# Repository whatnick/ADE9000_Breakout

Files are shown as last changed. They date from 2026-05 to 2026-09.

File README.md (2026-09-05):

# ADE9000 Breakout Board

Breadboard-compatible breakout for the Analog Devices [ADE9000](https://www.analog.com/en/products/ade9000.html) — a high-performance, multiphase energy and power quality monitoring IC.

The board follows the **test circuit from Figure 55 of the ADE9000 datasheet** (Rev. B, p. 28): all onboard passives (decoupling, RC anti-aliasing filters, crystal load caps, reset RC) are populated, power plus the analog channels are broken out to 0.1" headers, and the remaining digital signals are exposed on test pads to keep the board compact.

## 3D renders

These views are rendered from the populated KiCad assembly using the
project-local STEP models.

| Top isometric | Bottom isometric |
|---|---|
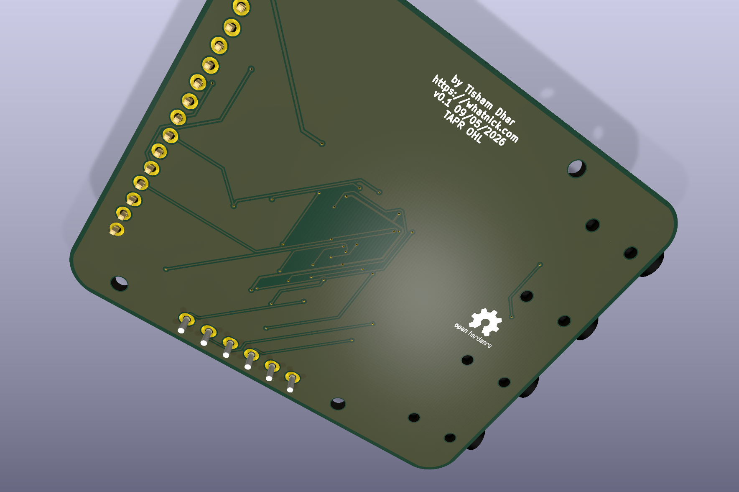
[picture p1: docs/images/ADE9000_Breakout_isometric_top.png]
ADE9000 breakout top isometric render
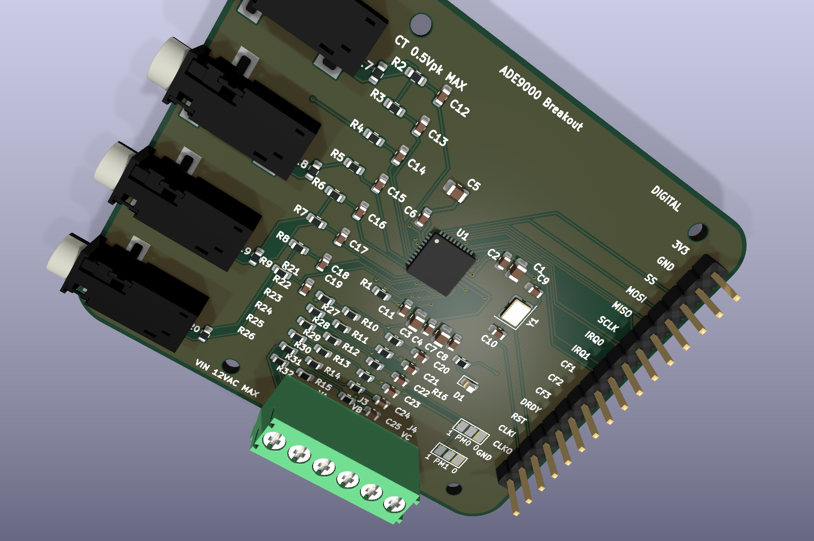
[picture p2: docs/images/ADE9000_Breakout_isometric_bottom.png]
ADE9000 breakout bottom isometric render
|  |  |

---

## Features

- **ADE9000** in 40-lead LFCSP (CP-40-7) package
- 3.3 V single-supply operation
- Onboard **24.576 MHz crystal** with 16 pF load caps (CLKIN/CLKOUT)
- Onboard **RC anti-aliasing filters** on all 7 analog input pairs (1 kΩ + 22 nF)
- Onboard **reset RC** (10 kΩ pull-up + 1 µF)
- Onboard **decoupling** on VDD, AVDDOUT, DVDDOUT, and REF per datasheet
- **CF2 activity LED** with 1 kΩ current-limit resistor
- **Power plus analog inputs** broken out to 0.1" headers
- **SPI, CF, IRQ, CLK, and RESET** exposed on test pads
- ATM90E36-style three-pad solder bridges for manual PM0/PM1 mode selection

---

## Pin Headers

### J1 — Power

| Pin | Signal | ADE9000 Pin | Description |
|-----|---|---|---|
| 1 | 3.3V | — | Power in |
| 2 | GND | — | Ground |

### J2 — Current Inputs (left side, top)

| Pin | Signal | ADE9000 Pin | Description |
|-----|---|---|---|
| 1 | IAP | 7 | Phase A current, positive |
| 2 | IAN | 8 | Phase A current, negative |
| 3 | IBP | 9 | Phase B current, positive |
| 4 | IBN | 10 | Phase B current, negative |
| 5 | ICP | 11 | Phase C current, positive |
| 6 | ICN | 12 | Phase C current, negative |
| 7 | INP | 13 | Neutral current, positive |
| 8 | INN | 14 | Neutral current, negative |

> Each input pair has a 1 kΩ series resistor and 22 nF cap to GND already fitted on board. Max differential input ±1 V / PGA gain.

### J3 — Voltage Inputs (left side, bottom)

| Pin | Signal | ADE9000 Pin | Description |
|-----|---|---|---|
| 1 | VAP | 20 | Phase A voltage, positive |
| 2 | VAN | 19 | Phase A voltage, negative |
| 3 | VBP | 22 | Phase B voltage, positive |
| 4 | VBN | 21 | Phase B voltage, negative |
| 5 | VCP | 24 | Phase C voltage, positive |
| 6 | VCN | 23 | Phase C voltage, negative |

> Each input pair has the same 1 kΩ + 22 nF RC filter as the current inputs.

### Test Pads — Digital I/O

| Pad | Signal | ADE9000 Pin | Description |
|-----|---|---|---|
| TP1 | SS | 40 | SPI slave select (active low) |
| TP2 | MOSI | 39 | SPI data in |
| TP3 | MISO | 38 | SPI data out |
| TP4 | SCLK | 37 | SPI clock (up to 20 MHz) |
| TP5 | IRQ0 | 31 | Interrupt output 0 (active low) |
| TP6 | IRQ1 | 32 | Interrupt output 1 (active low) |
| TP7 | CF1 | 33 | Calibration frequency output 1 |
| TP8 | CF2 | 34 | Calibration frequency output 2 / LED drive |
| TP9 | CF3_ZX | 35 | Zero-cross / CF3 output |
| TP10 | CF4_DREADY | 36 | Data-ready / event / CF4 output |
| TP11 | RESET | 6 | Reset (active low, RC-held high) |

---

## Power

- Supply **3.3 V** into the J1 3.3V pin (or the dedicated 3V3 pad).
- Current draw: ~15–17 mA in normal mode (PSM0).
- Onboard decoupling (per datasheet §Test Circuit):
  - **VDD** (pin 27): 10 µF + 0.1 µF ceramic to GND
  - **AVDDOUT** (pin 25): 4.7 µF + 0.1 µF ceramic to GND — **do not drive externally**
  - **DVDDOUT** (pin 3): 4.7 µF + 0.1 µF ceramic to GND — **do not drive externally**
  - **REF** (pin 16): 4.7 µF + 0.1 µF ceramic to REFGND (internal 1.25 V reference)

### PM0/PM1 mode bridges

`JP1` controls PM0 and `JP2` controls PM1. Each open three-pad jumper is marked
`1 PMx 0`: bridge the center pad to `1` for `+3V3`, or to `0` for `GND`.

| JP2 / PM1 | JP1 / PM0 | Selection |
|---|---|---|
| 0 | 0 | Normal operation |
| 0 | 1 | PM1:PM0 = `01` |
| 1 | 0 | PM1:PM0 = `10` |
| 1 | 1 | PM1:PM0 = `11` |

Bridge exactly one side of each jumper before powering the board. Never bridge
both sides, and do not leave a mode pin floating. Production boards intended
for normal operation should have the `0` side bridged on both JP1 and JP2.

---

## Clock

A 24.576 MHz crystal is fitted between CLKIN (pin 29) and CLKOUT (pin 30) with 16 pF load capacitors to GND. This matches the ADE9000's required ±30 ppm clock.

To use an external clock instead, remove the crystal, leave the load caps unpopulated, and drive CLKIN directly (3.3 V logic, 24.330–24.822 MHz, 45:55–55:45 duty cycle).

---

## SPI Interface

The ADE9000 uses **SPI mode 0** (CPOL=0, CPHA=0), MSB first, up to **20 MHz**.

| Signal | Direction (from MCU) | Notes |
|---|---|---|
| SCLK | Output | Max 20 MHz |
| MOSI | Output | 16-bit or 32-bit transfers |
| MISO | Input | |
| SS | Output | Assert low before each transfer |

All SPI pins are 3.3 V logic. Use a level shifter if connecting to a 5 V MCU.

---

## Analog Input Signal Conditioning

The onboard RC filter on each analog input pin:

```
Signal ──[ 1 kΩ ]──┬── IxP / VxP (ADE9000 pin)
                   │
                 [22 nF]
                   │
                  GND
```

This provides a first-order anti-aliasing LPF with fc ≈ 7.2 kHz, matching the ADC's −3 dB bandwidth. For CT or Rogowski coil inputs, drive the differential pair through an additional burden resistor or signal conditioning stage before these onboard filters.

---

## BOM Summary

Source purchasing fields live on the schematic symbols as `Manufacturer`, `MPN`, `DigiKey`, `Mouser`, and `Description` properties. Regenerate the grouped purchasing BOM with:

```powershell
& "C:\Program Files\KiCad\10.0\bin\python.exe" .\scripts\apply_bom_fields.py
& "C:\Program Files\KiCad\10.0\bin\python.exe" .\scripts\export_bom.py --html .\bom\ADE9000_Breakout_BOM.html
```

Generated outputs are available as [`bom/ADE9000_Breakout_BOM.csv`](bom/ADE9000_Breakout_BOM.csv), [`bom/ADE9000_Breakout_BOM.xlsx`](bom/ADE9000_Breakout_BOM.xlsx), and [`bom/ADE9000_Breakout_BOM.html`](bom/ADE9000_Breakout_BOM.html). The DigiKey and Mouser fields use distributor search URLs for the selected manufacturer MPNs so stock and packaging can be checked at order time.

| Ref | Value | Package | Notes |
|-----|---|---|---|
| U1 | ADE9000 | CP-40-7 LFCSP | Main IC |
| Y1 | 24.576 MHz | 3225 (3.2×2.5 mm) | ±30 ppm |
| C_CLKIN, C_CLKOUT | 16 pF | 0402 | Crystal load caps |
| C_VDD1 | 10 µF | 0805 | VDD bulk decoupling |
| C_VDD2, C_AVDD2, C_DVDD2, C_REF2 | 0.1 µF | 0402 | HF decoupling |
| C_AVDD1, C_DVDD1, C_REF1 | 4.7 µF | 0805 | LF decoupling |
| C_RST | 1 µF | 0402 | Reset RC |
| C_PM | 1 µF | 0402 | PM0 bypass |
| R_RST | 10 kΩ | 0402 | Reset pull-up |
| R_IAP…R_VCN (×14) | 1 kΩ | 0402 | Anti-aliasing series R |
| C_IAP…C_VCN (×7) | 22 nF | 0402 | Anti-aliasing cap (differential) |
| R_LED | 1 kΩ | 0402 | CF2 LED current limit |
| D_LED | Green LED | 0402 | CF2 activity indicator |

---

## Schematic

The KiCad schematic (`ADE9000_Breakout.kicad_sch`) implements Figure 55 of the datasheet with compact breakout constraints: only power and analog channels go to headers, while digital signals stay on test pads. Reference images and the datasheet are in [`docs/`](docs/).

---

## 3D CAD

Project-local STEP models for all populated ADE9000 board parts are stored in [`models/step/`](models/step/). The PCB references these files through `${KIPRJMOD}` so the 3D view and CAD export do not depend on a particular KiCad library installation.

The digital/debug header `J1` uses SparkFun's staggered `1x16_Locking` friction-fit footprint, vendored at [`footprints/SparkFun-Connector.pretty/1x16_Locking.kicad_mod`](footprints/SparkFun-Connector.pretty/1x16_Locking.kicad_mod) from `sparkfun/SparkFun-KiCad-Libraries` commit `14865e2`. It keeps the 2.54 mm header pitch but alternates pad positions by 0.127 mm so a standard breakaway male header can lock into the board without solder during bench use. The SparkFun library is licensed CC BY 4.0; attribution: SparkFun Electronics.

The stereo CT jacks use a black AP214-colored STEP model at [`models/step/Jack_3.5mm_CUI_SJ-3523-SMT_Horizontal.step`](models/step/Jack_3.5mm_CUI_SJ-3523-SMT_Horizontal.step), generated from the manufacturer `SJ-3523-SMT-TR` CAD ZIP in [`models/step/SJ_3523_SMT_TR.zip`](models/step/SJ_3523_SMT_TR.zip) with [`scripts/create_sj3523_smt_step.py`](scripts/create_sj3523_smt_step.py). The script bakes the DigiKey/Same Sky CAD into the KiCad footprint frame with the front barrel on the footprint's board-edge side, without adding artificial pad overlays. Do not substitute the through-hole `SJ1-3523N` model for this SMT footprint.

The voltage screw-terminal footprints use KiCad's 1x02 3.50 mm horizontal Phoenix STEP model as the closest installed mechanical equivalent for the 4Ucon footprint, with model-only offset `(-1.75, -0.05, 0)` to align the substitute body to the 4Ucon footprint outline.

A full board assembly STEP export is available at [`exports/step/ADE9000_Breakout.step`](exports/step/ADE9000_Breakout.step). Regenerate it with:

```powershell
& "C:\Program Files\KiCad\10.0\bin\kicad-cli.exe" pcb export step --force --subst-models --output "exports\step\ADE9000_Breakout.step" "ADE9000_Breakout.kicad_pcb"
```

---

## Resources

| Document | Path |
|---|---|
| ADE9000 Datasheet (Rev. B) | [`docs/ADE9000.pdf`](docs/ADE9000.pdf) |
| Test Circuit Reference | [`docs/images/test_ade9000.png`](docs/images/test_ade9000.png) |
| ADE9000 Product Page | https://www.analog.com/en/products/ade9000.html |
| ADE9000 Technical Reference Manual (UG-1098) | https://www.analog.com/media/en/technical-documentation/user-guides/ADE9000-UG-1098.pdf |
| Arduino Shield Eval (UG-1170) | https://www.analog.com/media/en/technical-documentation/user-guides/ev-ade9000shieldz-ug-1170.pdf |
| no-OS Driver | https://github.com/analogdevicesinc/no-OS/tree/main/drivers/meter/ade9000 |

---

## License

This hardware design is released under the [TAPR Open Hardware License v1.0](LICENSE). The PCB artwork includes a `TAPR OHL` notice on the back silkscreen.

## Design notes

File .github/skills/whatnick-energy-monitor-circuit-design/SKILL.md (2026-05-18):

---
name: whatnick-energy-monitor-circuit-design
description: "Use when: designing, reviewing, or regenerating energy-monitor schematics for ADE9000, ATM90E36, V9360, V9381, V9261F, MCP39xx, or similar metering breakouts. Covers datasheet circuits, analog input conditioning, current clamp burden/multiplier choices, power/reference/clock support circuits, connector policy, KiCad symbol connectivity, and ERC validation."
argument-hint: "target IC, schematic, or circuit block"
---

# Whatnick Energy Monitor Circuit Design

Use this skill for the electrical design of whatnick-style energy-monitor boards before PCB placement or routing. Start from the datasheet reference circuit, then adapt connector exposure and conditioning to the intended board format.

Reference designs:

- `c:/Users/tisha/dev/ADE9000_Breakout/ADE9000_Breakout.kicad_sch`
- `c:/Users/tisha/dev/ATM90E36_Breakout_KiCAD/ATM90E36_Breakout/ATM90E36_Breakout.kicad_sch`
- `c:/Users/tisha/dev/V93xx_Breakout/V9360_Breakout/V9360_Breakout.kicad_sch`
- `c:/Users/tisha/dev/V93xx_Breakout/V9381_Breakout/V9381_Breakout.kicad_sch`
- `c:/Users/tisha/dev/V9261F_Breakout/V9261F_Breakout.kicad_sch`
- `c:/Users/tisha/dev/MCP39xx_Breakout/MCP3909_Breakout/MCP3909_Breakout.kicad_sch`

## Circuit Intent

Build electrically correct monitor breakouts that are easy to instrument:

- Follow the target IC datasheet reference/test circuit first.
- Preserve project-local symbols and footprints for metering ICs; do not replace custom libraries with guessed global parts.
- Expose measurement inputs through connectors sized for the intended use: compact headers for small breakouts, stereo jacks and screw terminals for clamp/line-input bench boards.
- Keep debug/digital access compact and grouped, using a JST/debug connector or breadboard-friendly side header instead of scattering test pads across the board.
- Add onboard support circuits for supplies, reference outputs, reset, clock, and mode pins before optimizing the PCB.

## Datasheet-First Procedure

1. Identify the exact IC, package, and exposed-pad naming from the datasheet and part lookup.
2. Inspect the actual KiCad symbol geometry and pin names before wiring; never infer pin order from package drawings or symbol appearance.
3. Create or preserve a project-local symbol when the global KiCad library does not contain an exact part.
4. Implement the application circuit blocks:
   - supply input filtering and regulator/output decoupling
   - reference decoupling
   - analog anti-alias filters on voltage and current channels
   - reset pull-up/RC or supervisor connection where required
   - crystal, oscillator, or external clock network
   - mode straps and no-connects for datasheet-confirmed unused pins
5. Add `PWR_FLAG` symbols only where KiCad ERC needs proof that a net is driven.
6. Run ERC after every generated or bulk connectivity pass.

## Analog Input Conventions

Use explicit net names around every conditioning component:

- IC-side filtered nets use the IC signal name: `IAP`, `IAN`, `VAP`, `VAN`, and so on.
- Connector-side nets use a suffix such as `_J`, `_IN`, or the existing project convention when a series resistor separates the connector from the IC pin.
- Keep each differential or pseudo-differential pair easy to inspect in the schematic.
- Place shunt capacitors to `GND` only where the datasheet/filter design requires them.
- Keep voltage divider, burden, and multiplier resistor roles visually distinct from anti-alias series resistors.

Common patterns:

- ADE9000 Figure 55 style: 1 k series and 22 nF shunt anti-alias filters on analog inputs; decouple VDD, AVDDOUT, DVDDOUT, and REF.
- V93XX compact style: small series resistors and shunt capacitors near the monitor IC; preserve datasheet-specific values.
- ATM-style clamp boards: CT jack inputs feed conditioning networks, and voltage inputs use screw terminals and divider/filter networks sized for the measurement range.

## Current Clamp Support

When supporting YHDC or similar current-output clamps:

- Add a clearly labeled burden/multiplier resistor across each jack-side current pair.
- Keep burden resistors close to the input connector but before the IC-side anti-alias network.
- Use explicit pair nets such as `IAP_J`/`IAN_J`, `IBP_J`/`IBN_J`, `ICP_J`/`ICN_J`, and `INP_J`/`INN_J`.
- For the ADE9000 ATM-style board, R17-R20 are 2.4R 0603 burden/multiplier resistors across the four current jack pairs for hand assembly.

## Digital And Debug Policy

Choose the debug exposure based on board format:

- Compact breakouts: put power and analog measurement pins on 0.1 inch headers; place CF, IRQ, reset, clock, and other low-use digital signals on named bottom-side test pads.
- Compact ADE9000 JST policy: use `J1` as a 6-pin JST-SH connector for `+3V3`, `GND`, `SS`, `MOSI`, `MISO`, and `SCLK`; keep CF/IRQ/CLK/RESET on named test pads.
- Larger ATM-style boards: aggregate digital signals on one board side with a breadboard-friendly 0.1 inch header so logic-analyzer and MCU hookup is obvious.
- Keep signal names literal on debug connectors and test pads: `SS`, `MOSI`, `MISO`, `SCLK`, `IRQ0`, `CF1`, `RESET`, `CLKIN`, etc.

## KiCad Connectivity Rules

For generated or MCP-edited schematics, connectivity must be physical, not label-only:

- Prefer MCP `connect_to_net` when it uses the exact pin endpoint.
- If scripting manually, emulate `connect_to_net`: pin endpoint -> short wire stub -> net label at the stub end.
- Use exact pin endpoints for IC pins, passives, connectors, and test pads.
- Do not place bare labels on passive pin bodies or guessed component coordinates; this caused ERC-open nets in the ADE9000 work.
- Add no-connect markers only to datasheet-confirmed unused pins.

## ERC Validation

Run KiCad 10 ERC from the project root:

```powershell
& "C:\Program Files\KiCad\10.0\bin\kicad-cli.exe" sch erc --format json --output erc.json .\ADE9000_Breakout.kicad_sch
```

Acceptable schematic state:

- Zero ERC errors.
- No floating labels or unintended `multiple_net_names` violations.
- No unconnected monitor IC pins unless they have datasheet-backed no-connect markers.
- Warnings are understood and documented. `endpoint_off_grid` is placement/grid hygiene; fix alignment before changing proven connectivity.

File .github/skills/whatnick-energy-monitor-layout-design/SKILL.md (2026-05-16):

---
name: whatnick-energy-monitor-layout-design
description: "Use when: placing components, connectors, references, markings, or test pads on whatnick-style energy-monitor PCBs. Covers analog/digital partitioning, connector placement, decoupling placement, CT jack and screw terminal layout, silkscreen/reference rules, and deterministic KiCad Python placement workflows."
argument-hint: "target board or placement task"
---

# Whatnick Energy Monitor Layout Design

Use this skill after the circuit is defined and before routing. The goal is a board that is easy to wire, easy to probe, and friendly to the autorouter while keeping analog measurement paths short and readable.

Reference layouts:

- `c:/Users/tisha/dev/ADE9000_Breakout/ADE9000_Breakout.kicad_pcb`
- `c:/Users/tisha/dev/ADE9000_Breakout/scripts/place_pcb.py`
- `c:/Users/tisha/dev/ADE9000_Breakout/scripts/move_refs_to_silkscreen.py`
- `c:/Users/tisha/dev/ATM90E36_Breakout_KiCAD/ATM90E36_Breakout/ATM90E36_Breakout.kicad_pcb`
- `c:/Users/tisha/dev/V93xx_Breakout/V9360_Breakout/V9360_Breakout.kicad_pcb`
- `c:/Users/tisha/dev/V93xx_Breakout/V9381_Breakout/V9381_Breakout.kicad_pcb`

## Placement Intent

- Place the monitor IC first, usually near the center, with pin banks facing their related circuits.
- Keep analog conditioning between the field connector and the IC pin it serves.
- Put current inputs, voltage inputs, power/debug headers, and digital headers on board edges with readable pin order from the board edge.
- Keep high-touch connectors mechanically accessible; avoid burying screw terminals, jacks, or debug headers behind tall parts.
- Keep clock parts close to clock pins and away from noisy digital routing.
- Keep decoupling capacitors tight to the IC supply/reference pins with very short GND return paths.
- Use deterministic KiCad Python scripts for nontrivial board placement so the board can be regenerated.

## Analog And Digital Partitioning

- Put analog input connectors on one side or along the edge nearest the analog pin bank.
- Put digital/debug signals on the opposite side when board size allows.
- Keep SPI/UART/CF/IRQ/reset routing corridors away from current and voltage input filters.
- In compact boards, bottom-side test pads can reduce front-side crowding. In larger bench boards, prefer a grouped side header for digital signals.
- For ATM-style energy boards, stereo current jacks and voltage screw terminals should be grouped by channel and labeled so wiring order is obvious.

## Connector Placement Patterns

- Compact V93XX style: one 0.1 inch header and bottom-side test pads on a small rounded board.
- Compact ADE9000 JST style: `J1` JST-SH for power/SPI, `J2`/`J3` for analog pairs, bottom-edge test pads for CF/IRQ/clock/reset.
- ATM-style bench board: stereo jacks for current clamp inputs, screw terminals for voltage inputs, and a 0.1 inch digital/debug header along one side for breadboard or logic-analyzer access.
- Keep connector references visible on silkscreen and orient values on Fab only.

## Decoupling And Support Placement

- Place each decoupling capacitor adjacent to its associated IC pin; do not gather decouplers into a remote cluster.
- Pair AVDDOUT/DVDDOUT/REF capacitors with their pins and nearby GND access.
- Keep oscillator/crystal parts short, symmetric, and isolated from long digital traces.
- Place reset pull-ups/caps near reset pins unless a connector-driven reset path needs edge access.
- Place burden/multiplier resistors near the jack-side current pair before the anti-alias path enters the IC-side filter rows.

## Reference And Silkscreen Rules

- Reference designators live on the matching silkscreen layer: `F.SilkS` for front-side footprints and `B.SilkS` for back-side footprints.
- Values stay on Fab layers to keep silkscreen readable.
- Mounting-hole `H*` references and values are intentionally hidden.
- Keep every component, connector, and test-pad reference visible unless it is a mounting hole.
- Move or rotate references to avoid pads, copper, board edges, and other text.
- Use `scripts/move_refs_to_silkscreen.py` with KiCad 10 Python to bulk-migrate references from Fab to silkscreen.

Default silkscreen style:

- Compact labels: 0.8 mm text height and 0.2 mm stroke when DRC/project rules allow.
- Board identity on front when space allows.
- Attribution/version/OSHW logo on back after placement is stable.

## Deterministic KiCad Python Pattern

Run placement scripts with KiCad 10 Python:

```powershell
& "C:\Program Files\KiCad\10.0\bin\python.exe" .\scripts\place_pcb.py
```

Script guidelines:

- Define board geometry and connector/channel constants near the top.
- Use helpers such as `place`, `place_bottom`, and `set_net` instead of repeating coordinate logic.
- Load exact footprints with `pcbnew.FootprintLoad` when library naming differs from schematic symbols.
- For ADE9000, KiCad 10 lacks the exact `EP4.27x4.27mm` QFN footprint; load the `EP4.6x4.6mm` footprint and resize/renumber the exposed pad to `EP`.
- Place refs before adding new Edge.Cuts or mounting-hole shapes if KiCad SWIG collections are fragile.
- If new footprint fields need to be hidden after insertion, post-process the serialized `.kicad_pcb` properties when SWIG field objects are unstable.

PowerShell note: do not use bash heredocs. Use checked-in scripts or `python -c` one-liners.

## Layout DRC Gate

Before routing, DRC should have no placement/mechanical blockers:

- no `courtyards_overlap`
- no `copper_edge_clearance`
- no `hole_clearance` or `hole_to_hole`
- no `pth_inside_courtyard` or `npth_inside_courtyard`
- no `silk_overlap`, `silk_over_copper`, or `silk_edge_clearance` caused by new placement

Unconnected items are expected before routing; all other DRC issues should be understood before exporting DSN.

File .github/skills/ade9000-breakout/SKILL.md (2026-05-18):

---
name: ade9000-breakout
description: "Use when: making ADE9000_Breakout-specific schematic, PCB, routing, validation, or script changes. Layer this project overlay on top of the whatnick energy-monitor circuit-design, layout-design, routing, and pcb-size-shape skills. Covers ADE9000 Figure 55, KiCad 10 commands, local scripts, current ATM-style board facts, and known MCP/KiCad pitfalls."
argument-hint: "ADE9000 schematic, PCB, routing, or validation task"
---

# ADE9000 Breakout Project Overlay

Use this skill for ADE9000_Breakout-specific facts. For reusable design principles, also load the relevant topic skill:

- Circuit/schematic work: `whatnick-energy-monitor-circuit-design`
- BOM and MPN sourcing: `whatnick-energy-monitor-bom-sourcing`
- Component placement and silkscreen: `whatnick-energy-monitor-layout-design`
- Routing, GND planes, netclasses, and DRC: `whatnick-energy-monitor-routing`
- Board envelope, mounting holes, and connector edge plan: `whatnick-energy-monitor-pcb-size-shape`
- 3D model placement and STEP export: `whatnick-energy-monitor-layout-design`

## Current Board Intent

The current board is an ATM90E36-style ADE9000 bench breakout, not the older tiny header-only board.

- Board envelope: 65 mm x 55 mm with rounded corners and four M2 NPTH mounting holes.
- Current inputs: stereo jack style connectors, with YHDC current-output clamp support.
- Voltage inputs: screw terminals.
- Voltage screw-terminal inputs are scaled for 12 VAC AC/AC transformer inputs using 100 kOhm high-side divider resistors and 2.49 kOhm shunts before the existing 1 k / 22 nF ADE9000 anti-alias filters. Keep small passives as 0603 on F.Cu for easier hand soldering unless a specific assembly constraint overrides it.
- Digital/debug signals: aggregated on one side for breadboard/logical analyzer access.
- `J1` uses the project-local SparkFun `1x16_Locking` staggered/friction-fit footprint from `footprints/SparkFun-Connector.pretty`, placed at `(184.873, 86.1)` with -90 degree rotation so odd-numbered pads stay on the old `x=185.0` route centerline and pins 2-16 run downward.
- GND planes: filled on F.Cu and B.Cu.
- Power routing: `+3V3`, `AVDDOUT`, and `DVDDOUT` use the `Power` netclass with 0.25 mm tracks and 0.50/0.25 mm vias.
- 3D CAD: populated parts use project-local STEP models under `models/step/`; full assembly export lives at `exports/step/ADE9000_Breakout.step`.
- The CT jack STEP model must match the SMT `Jack_3.5mm_CUI_SJ-3523-SMT_Horizontal` footprint; do not substitute the through-hole `SJ1-3523N` model.
- Strip CT jack footprint outlines from F.SilkS on this board; the jacks intentionally overhang the left board edge, and separate `CTA`/`CTB`/`CTC`/`CTN` labels carry the readable silkscreen marking.
- Voltage screw terminals use the Phoenix 1x02 P3.50 mm STEP as a 4Ucon substitute with model offset `(-1.75, -0.05, 0)`; keep pads at the continuous 3.5 mm row positions `J2=155`, `J3=162`, `J4=169`.

The previous compact/JST policy remains useful historical context:

- Compact `J1`: 6-pin JST-SH for `+3V3`, `GND`, `SS`, `MOSI`, `MISO`, and `SCLK`.
- Compact `J2`/`J3`: analog current/voltage inputs.
- Compact `TP5` through `TP13`: CF, IRQ, clock, and reset signals on the lower board edge.
- Do not recreate obsolete compact `TP1` through `TP4` unless intentionally reverting to the older topology.

## Circuit Facts

- Follow the ADE9000 datasheet Figure 55 support circuit unless the user explicitly changes topology.
- `ADE9000_Breakout.kicad_sym` is the authoritative source for custom symbol geometry.
- The ADE9000 exposed-pad pin number is `EP`.
- Anti-alias filters use 1 k series resistors and 22 nF shunt capacitors on analog input paths.
- VDD, AVDDOUT, DVDDOUT, and REF need local decoupling near U1.
- Clock uses a 24.576 MHz crystal with load capacitors unless using an external clock.
- PM0/PM1 are grounded for normal operating mode.
- YHDC current-output clamp support uses R17-R20, 2.4R 0603 burden/multiplier resistors across the jack-side current pairs.
- Voltage terminal support uses R21-R26 as 100 kOhm high-side divider resistors and R27-R32 as 2.49 kOhm shunts, producing about 0.41 V peak at the divider node from a 12 VAC RMS transformer input before the 1 k ADE9000 filter resistor.

## Schematic Generation Rules

- Inspect actual symbol pin locations before assigning nets.
- For U1 and all passives/connectors/test pads, connect by exact pin endpoint.
- Prefer MCP `connect_to_net` when it uses the exact pin endpoint.
- If scripting raw connectivity, use pin endpoint -> short wire stub -> net label at the stub end.
- Do not use label-only connectivity on passive pins; it looked connected but left pins ERC-open in this project.
- Add `no_connect` only to intentionally unused pins.
- Run KiCad ERC immediately after rewiring.

ERC interpretation:

- `pin_not_connected` means the generator failed electrically.
- `multiple_net_names` usually means two labeled stubs were accidentally merged.
- `endpoint_off_grid` is placement/grid hygiene; fix grid/placement before reworking proven connectivity.

## PCB Script Flow

Primary scripts:

- `scripts/rewire_schematic.py`: deterministic schematic regeneration.
- `scripts/apply_bom_fields.py`: deterministic schematic sourcing fields for Manufacturer, MPN, DigiKey, Mouser, and Description.
- `scripts/export_bom.py`: grouped CSV/XLSX/HTML BOM export from schematic fields.
- `scripts/place_pcb.py`: deterministic footprint/net assignment and placement.
- `scripts/apply_mechanical.py`: rounded outline, M2 holes, and board markings.
- `scripts/move_refs_to_silkscreen.py`: visible reference designators on matching silkscreen layers.
- `scripts/clear_routes_text.py`: remove old `(segment ...)` and `(via ...)` blocks before rerouting.
- `scripts/clear_zones_text.py`: remove old `(zone ...)` blocks before rerouting.
- `scripts/apply_power_planes.py`: add F.Cu/B.Cu GND planes and enforce thicker power copper.

Run scripts with KiCad 10 Python:

```powershell
& "C:\Program Files\KiCad\10.0\bin\python.exe" .\scripts\place_pcb.py
```

PowerShell note: use semicolons for command chaining and avoid bash heredocs.

## Routing Facts

- Clear stale routes and zones before a fresh autoroute.
- Export fresh DSN with KiCad Python `pcbnew.ExportSpecctraDSN`; avoid stale MCP DSN export state.
- Route with the `Power` netclass already present in `.kicad_pro`; post-widening already-routed 0.15 mm power tracks caused clearance errors.
- Use GND planes instead of widening every GND trace.
- For KiCad 10 vias, avoid `PCB_VIA.GetWidth()` without layer context; use `GetFrontWidth()` or set width directly.
- `scripts/apply_power_planes.py` uses solid GND zone connections to avoid a starved thermal on U1 pad 28.

Installed Freerouting context:

- Router jar: `C:/Users/tisha/AppData/Roaming/kicad/10.0/freerouting/freerouting.jar`
- JRE 25: `C:/Users/tisha/AppData/Roaming/kicad/10.0/freerouting/jre/jdk-25.0.3+9-jre/bin/java.exe`

## Validation Commands

STEP export:

```powershell
& "C:\Program Files\KiCad\10.0\bin\kicad-cli.exe" pcb export step --force --subst-models --output exports\step\ADE9000_Breakout.step .\ADE9000_Breakout.kicad_pcb
```

ERC:

```powershell
& "C:\Program Files\KiCad\10.0\bin\kicad-cli.exe" sch erc --format json --output erc.json .\ADE9000_Breakout.kicad_sch
```

DRC:

```powershell
& "C:\Program Files\KiCad\10.0\bin\kicad-cli.exe" pcb drc --format json --output drc.json .\ADE9000_Breakout.kicad_pcb
```

Expected final PCB state:

- Zero DRC errors.
- Zero unconnected items.
- Remaining warnings are known library/text/silkscreen warnings unless the task is specifically to eliminate them.

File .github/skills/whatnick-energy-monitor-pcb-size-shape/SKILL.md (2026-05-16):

---
name: whatnick-energy-monitor-pcb-size-shape
description: "Use when: choosing board size, outline shape, connector edge allocation, mounting holes, rounded corners, or compact versus ATM-style mechanical form for whatnick energy-monitor PCBs. Covers V93XX compact boards, MCP3909 rounded corners, ADE9000 compact/JST and ATM-style board envelopes, M2 holes, and mechanical DRC constraints."
argument-hint: "target board, enclosure, or mechanical format"
---

# Whatnick Energy Monitor PCB Size And Shape

Use this skill when deciding the board envelope, rounded corners, mounting holes, connector edge plan, or compact-versus-bench-board form factor.

Reference boards:

- `c:/Users/tisha/dev/V93xx_Breakout/V9360_Breakout/V9360_Breakout.kicad_pcb`
- `c:/Users/tisha/dev/V93xx_Breakout/V9381_Breakout/V9381_Breakout.kicad_pcb`
- `c:/Users/tisha/dev/MCP39xx_Breakout/MCP3909_Breakout/MCP3909_Breakout.kicad_pcb`
- `c:/Users/tisha/dev/ATM90E36_Breakout_KiCAD/ATM90E36_Breakout/ATM90E36_Breakout.kicad_pcb`
- `c:/Users/tisha/dev/ADE9000_Breakout/ADE9000_Breakout.kicad_pcb`
- `c:/Users/tisha/dev/ADE9000_Breakout/scripts/apply_mechanical.py`

## Form Factor Choice

Choose the board size from how the user will connect to it:

- Compact breakout: use when the goal is a small module exposing IC power and measurement pins with minimal debug access.
- Compact JST debug board: use when SPI/debug needs a reliable cable connector but the board should remain small.
- ATM-style bench board: use when the board needs stereo CT jacks, screw terminals, grouped digital header access, and more comfortable probing.
- Do not force a compact outline when connectors or analog filters cause bad routing, inaccessible labels, or fragile probing.

## Compact Board Style

V9360, V9381, MCP3909, and the compact ADE9000 revisions are the small-board references.

- V93XX envelope is about 38.2 mm x 28.04 mm including edge stroke.
- Compact ADE9000 JST revision used about 38.1 mm x 38.0 mm.
- Keep headers on edges and test pads on the bottom side when front-side space is tight.
- Put optional logos and attribution on B.SilkS after routing space is known.
- Keep copper, test pads, mounting holes, and silkscreen clear of rounded or chamfered edges.

## ATM-Style Bench Board

Use the ATM90E36-style layout when the energy monitor board is a wiring/probing platform rather than a tiny module.

- Allocate one edge or side region for digital/debug signals on a 0.1 inch breadboard-friendly header.
- Group current inputs by channel using stereo jacks or similarly robust connectors.
- Group voltage inputs on screw terminals with readable phase/neutral order.
- Leave room for burden/multiplier resistors near current jacks and filter rows near the IC.
- Use the larger board area to reduce routing congestion and improve silkscreen readability, not to scatter circuit blocks.
- The current ADE9000 ATM-style board uses a 65 mm x 55 mm envelope with current jacks, voltage screw terminals, digital header, M2 holes, and GND planes.

## Rounded Corners And Mounting Holes

Use MCP3909 as the rounded-corner style reference and ADE9000 as the local M2 implementation reference.

- Use rounded corners when the board will be handled as a bench module.
- 5.08 mm corner radius is the established rounded-corner visual pattern.
- Use four M2 NPTH holes when board space allows.
- M2 holes should be NPTH circular pads with 2.2 mm drill and 2.2 mm pad size, no net, excluded from BOM and position files.
- Hide mounting-hole references and values by design.
- Keep mounting holes outside component courtyards and away from copper, zones, silkscreen, and connector keepouts.

## Edge Allocation

- Put field wiring connectors where cables naturally leave the board.
- Keep analog connector edges away from digital headers when board size allows.
- Reserve a clean routing corridor between each connector group and its IC pin bank.
- Put bottom-side test pads along a board edge rather than mid-board when they need routing access.
- For the ADE9000 compact JST revision, bottom-edge `TP5` through `TP13` preserve the SPI/JST fanout corridor; the older mid-board cluster blocks routing.

## Mechanical Scripts

For ADE9000 mechanical finishing:

```powershell
& "C:\Program Files\KiCad\10.0\bin\python.exe" .\scripts\apply_mechanical.py .\ADE9000_Breakout.kicad_pcb
```

Script principles:

- Keep board bbox constants explicit.
- Rebuild Edge.Cuts deterministically.
- Add mounting holes reproducibly.
- Reapply board markings after outline/hole regeneration when the local script owns those markings.
- Avoid re-querying fragile KiCad SWIG collections after adding/removing board drawings; collect what is needed before mutation.

## Mechanical DRC Gate

After changing size, shape, holes, or connector placement, DRC must not introduce:

- `copper_edge_clearance`
- `hole_clearance`
- `hole_to_hole`
- `npth_inside_courtyard`
- `pth_inside_courtyard`
- `courtyards_overlap`
- `silk_edge_clearance`
- `silk_overlap`
- `silk_over_copper`

If board size changes cause new routing congestion, revisit connector edge allocation before relaxing clearances.

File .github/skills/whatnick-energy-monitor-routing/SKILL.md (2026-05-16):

---
name: whatnick-energy-monitor-routing
description: "Use when: routing, autorouting, adding ground planes, configuring net classes, importing SES files, or validating DRC for whatnick-style energy-monitor PCBs. Covers analog routing priorities, power trace widths, GND planes, Freerouting workflow, KiCad 10 DSN/SES handling, and zero-error DRC expectations."
argument-hint: "target board or routing task"
---

# Whatnick Energy Monitor Routing

Use this skill once placement is DRC-clean. Route critical analog, clock, power, and return paths deliberately, and use autorouting only with rules that match the intended copper widths.

Reference scripts and boards:

- `c:/Users/tisha/dev/ADE9000_Breakout/ADE9000_Breakout.kicad_pcb`
- `c:/Users/tisha/dev/ADE9000_Breakout/ADE9000_Breakout.kicad_pro`
- `c:/Users/tisha/dev/ADE9000_Breakout/scripts/clear_routes_text.py`
- `c:/Users/tisha/dev/ADE9000_Breakout/scripts/clear_zones_text.py`
- `c:/Users/tisha/dev/ADE9000_Breakout/scripts/apply_power_planes.py`

## Routing Priorities

1. Confirm placement DRC is clean except expected unconnected items.
2. Route current and voltage input pairs with short, tidy paths through their filters.
3. Route reference, regulator output, and decoupling connections with short return loops.
4. Route clock/crystal nets short and away from SPI/CF/IRQ runs.
5. Route digital/debug signals after analog and clock paths have stable corridors.
6. Add or refill GND planes after critical routes are stable.
7. Run DRC and inspect both clearance errors and unconnected items.

## Net Classes And Widths

Keep `.kicad_pro` rules aligned with the board being validated; KiCad CLI DRC uses project constraints.

Compact QFN breakout rules:

- Default: 0.15 mm track width, 0.15 mm clearance, 0.45 mm vias, 0.20 mm via drills.
- This routes dense ADE9000 compact/JST layouts cleanly when test pads are placed along the lower board edge.

ATM-style ADE9000 rules:

- Default signal routing can remain 0.15 mm/0.15 mm for dense IC fanout.
- Use a `Power` netclass for `+3V3`, `AVDDOUT`, and `DVDDOUT` before routing:
  - 0.25 mm tracks
  - 0.50 mm vias
  - 0.25 mm via drills
  - 0.15 mm clearance
- Do not post-widen dense 0.15 mm routes blindly; it creates avoidable clearance errors. Export DSN after the Power netclass is in the project.
- Treat `REF` as a precision/reference node, not a bulk power rail, unless the circuit specifically requires otherwise.
- Use GND planes for return copper; do not widen every `GND` segment in dense analog areas.

## Ground Planes

- Use filled GND zones on both copper layers when board area allows.
- Keep zones inset from board edges and mounting holes enough to avoid copper-edge and hole-clearance issues.
- Refill zones after every routing or mechanical change.
- For the ADE9000 ATM-style board, `scripts/apply_power_planes.py` adds F.Cu/B.Cu GND planes and enforces thicker power routing.
- Solid GND zone pad connections avoid the starved thermal on ADE9000 U1 pad 28; thermal relief can be used elsewhere only when DRC remains clean.

## Freerouting Workflow

Use fresh DSN/SES files. Avoid stale in-memory board state.

```powershell
& "C:\Program Files\KiCad\10.0\bin\python.exe" .\scripts\clear_routes_text.py .\ADE9000_Breakout.kicad_pcb
& "C:\Program Files\KiCad\10.0\bin\python.exe" .\scripts\clear_zones_text.py .\ADE9000_Breakout.kicad_pcb
& "C:\Program Files\KiCad\10.0\bin\python.exe" -c "import pcbnew; board=pcbnew.LoadBoard(r'ADE9000_Breakout.kicad_pcb'); pcbnew.ExportSpecctraDSN(board, r'ADE9000_Breakout.dsn')"
& "C:\Users\tisha\AppData\Roaming\kicad\10.0\freerouting\jre\jdk-25.0.3+9-jre\bin\java.exe" -jar "C:\Users\tisha\AppData\Roaming\kicad\10.0\freerouting\freerouting.jar" -de .\ADE9000_Breakout.dsn -do .\ADE9000_Breakout.ses -mp 100
& "C:\Program Files\KiCad\10.0\bin\python.exe" -c "import pcbnew; path=r'ADE9000_Breakout.kicad_pcb'; board=pcbnew.LoadBoard(path); pcbnew.ImportSpecctraSES(board, r'ADE9000_Breakout.ses'); pcbnew.SaveBoard(path, board)"
```

After SES import, reapply mechanical/marking scripts if the board flow requires them, then add planes and run DRC.

Installed Freerouting context for this machine:

- Router jar: `C:/Users/tisha/AppData/Roaming/kicad/10.0/freerouting/freerouting.jar`
- JRE 25: `C:/Users/tisha/AppData/Roaming/kicad/10.0/freerouting/jre/jdk-25.0.3+9-jre/bin/java.exe`

## KiCad 10 API Notes

- Export DSN with KiCad Python `pcbnew.ExportSpecctraDSN`; the MCP DSN exporter can use stale copper.
- Import SES with `pcbnew.ImportSpecctraSES`.
- For KiCad 10 vias, do not call `PCB_VIA.GetWidth()` without a layer-aware context. Use `GetFrontWidth()` or set via width directly.
- Clear zones with `scripts/clear_zones_text.py` before rerouting if old filled zones interfere with DSN export or DRC diagnosis.

## DRC Validation

Run KiCad 10 DRC from the project root:

```powershell
& "C:\Program Files\KiCad\10.0\bin\kicad-cli.exe" pcb drc --format json --output drc.json .\ADE9000_Breakout.kicad_pcb
```

Final routed boards must have:

- Zero DRC errors.
- Zero unconnected items.
- No non-library violations introduced by routing, pours, holes, or silkscreen.
- Remaining warnings are understood, usually `lib_footprint_mismatch`, text size, or legacy silkscreen warnings unless the current task is to eliminate them.

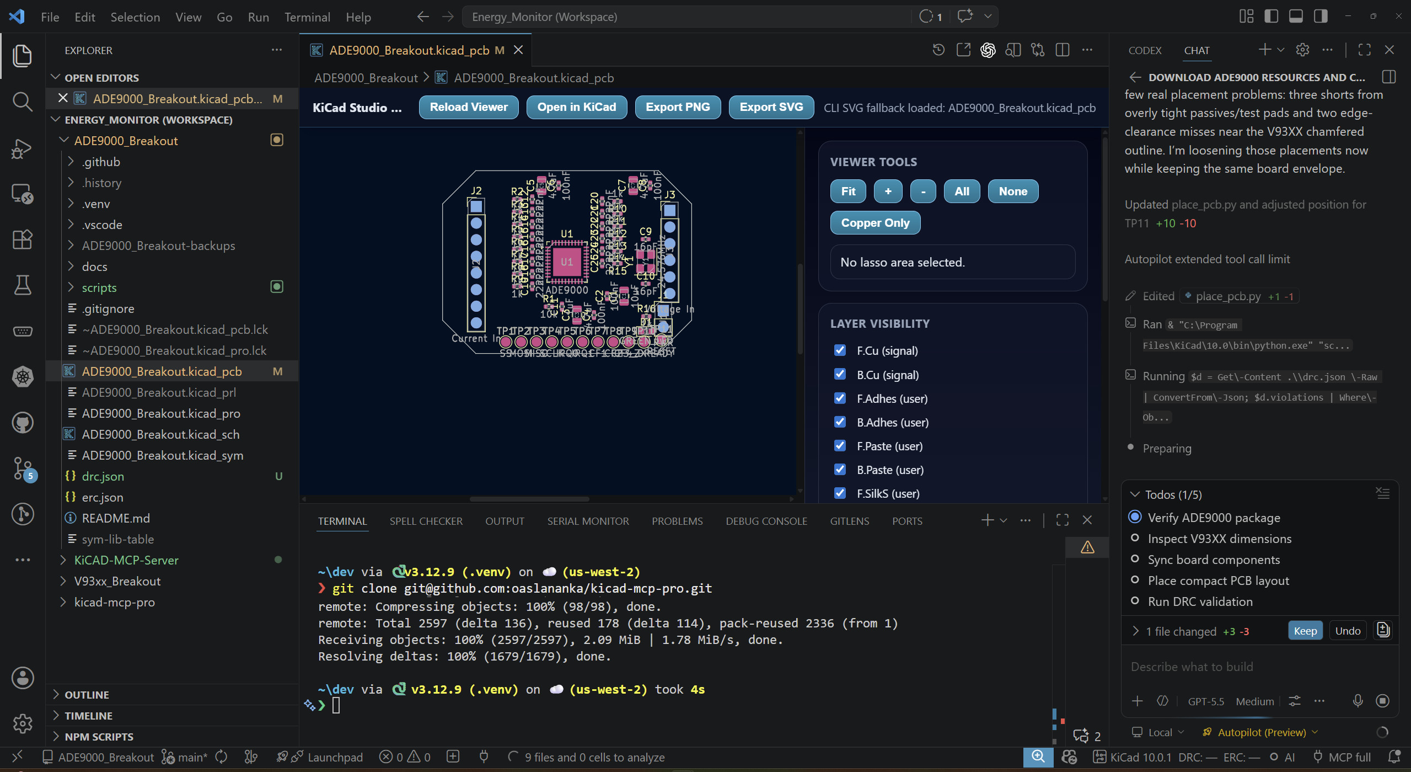
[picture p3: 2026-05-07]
docs/images/ai_aided_pcb.png

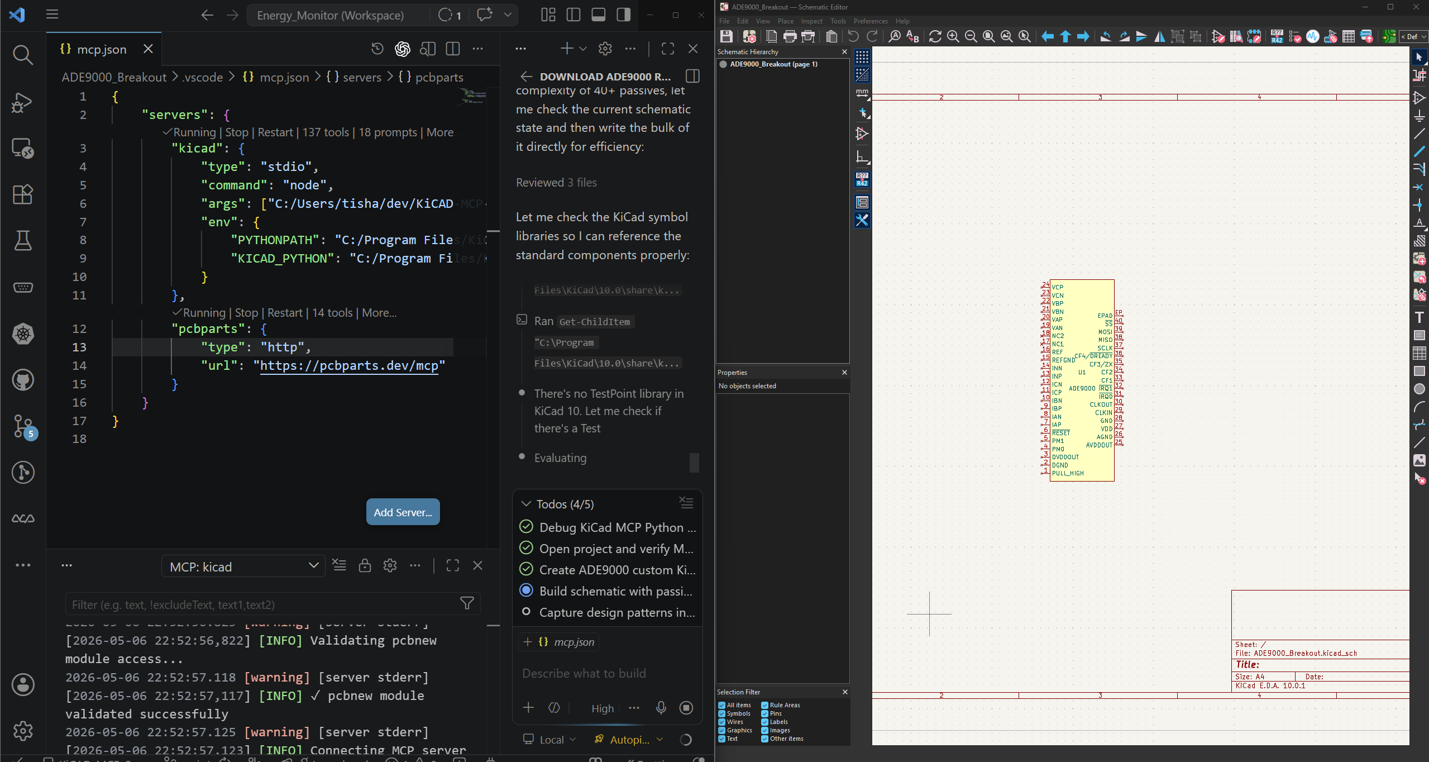
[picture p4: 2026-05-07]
docs/images/ai_aided_kicad.png

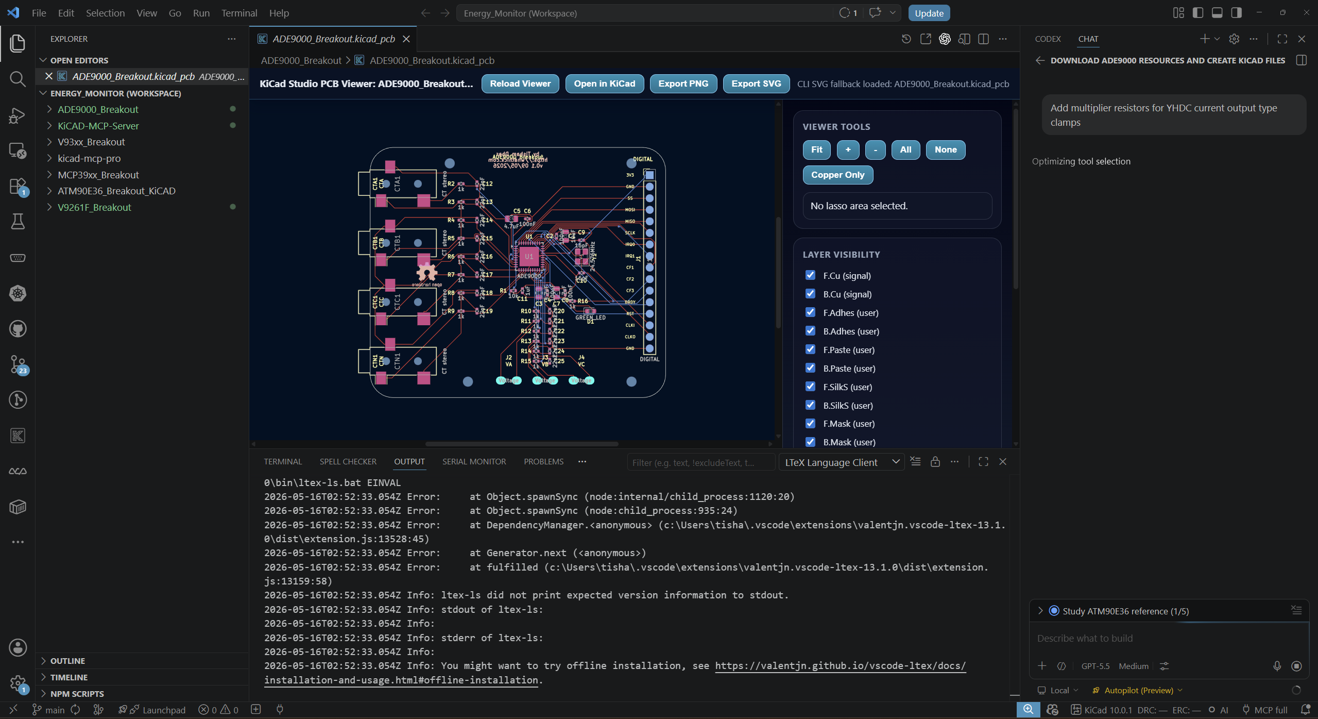
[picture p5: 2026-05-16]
docs/images/pivot_to_inputs_clamp.png

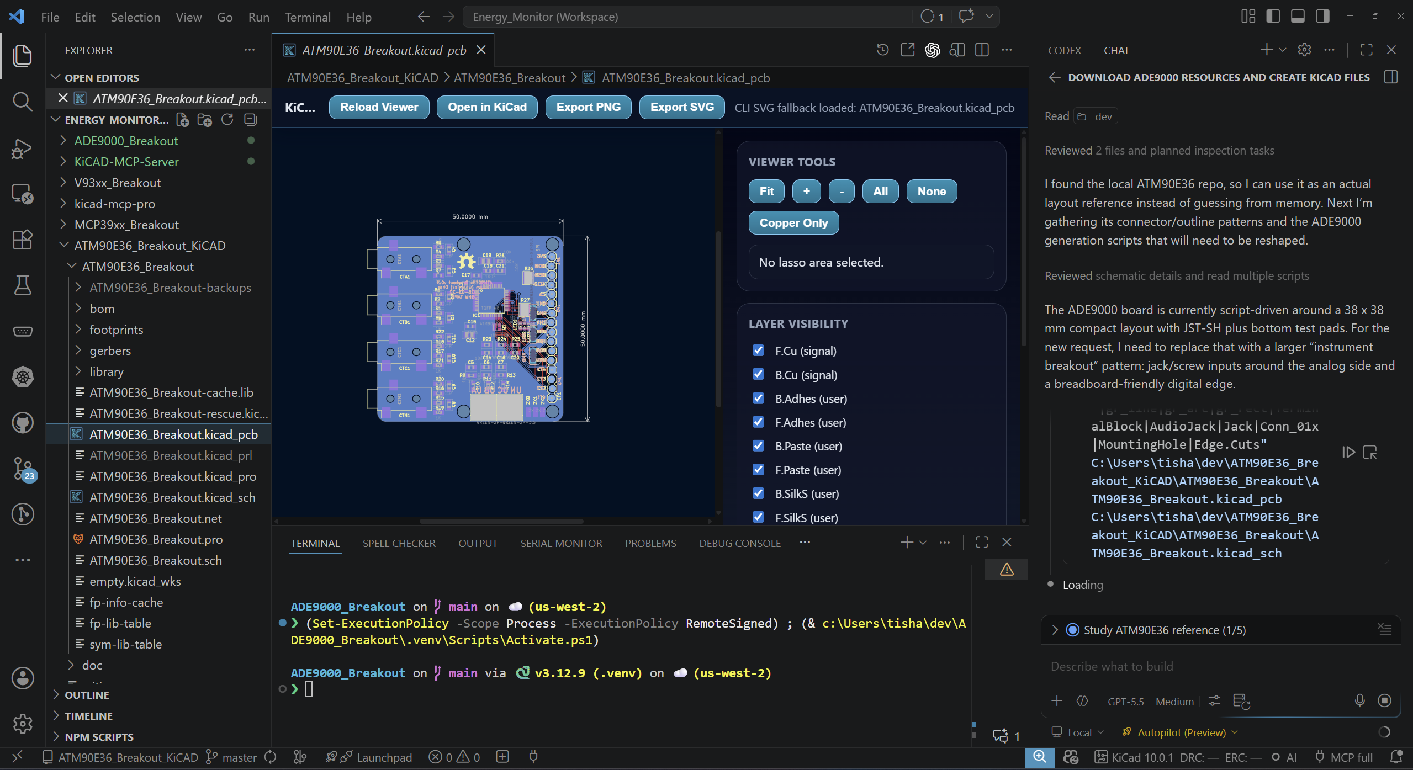
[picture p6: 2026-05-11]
docs/images/pivot_to_larger_board.png

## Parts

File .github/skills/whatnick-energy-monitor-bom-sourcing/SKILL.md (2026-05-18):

---
name: whatnick-energy-monitor-bom-sourcing
description: "Use when: choosing MPNs, creating BOMs, adding schematic sourcing fields, selecting DigiKey/Mouser parts, or standardizing passives/connectors across whatnick energy-monitor boards for bulk reel buying and reuse. Covers preferred common values, value normalization, substitution policy, distributor fields, and CSV/XLSX BOM export discipline."
argument-hint: "BOM, MPNs, DigiKey/Mouser sourcing, common passives, reel buying"
---

# Whatnick Energy Monitor BOM Sourcing

Use this skill when adding, reviewing, or regenerating BOM fields for whatnick energy-monitor boards. The sourcing goal is to reuse common values and manufacturers across boards so frequently used parts can be bought as reels and consumed across designs.

## Core Policy

- Put purchasing data on schematic symbols, not only in exported spreadsheets.
- Use the same preferred MPN for the same electrical value, package, dielectric, tolerance, and voltage rating wherever possible.
- Prefer reel-friendly commodity passives from stable high-volume families before optimizing for a one-off cheapest line item.
- Keep exact or mechanically constrained connectors as exact MPNs; do not substitute connectors just to share a line item if footprint, height, pitch, pinout, or 3D fit changes.
- Use distributor search URLs in `DigiKey` and `Mouser` fields unless a verified order-code field already exists in that project.
- Do not change precision, voltage rating, dielectric, power rating, package size, or temperature behavior to force reuse.
- Preserve measurement accuracy: burden, shunt, divider, reference, oscillator, and anti-alias parts may need tighter tolerance or lower tempco than generic passives.

## Preferred Common Parts

Use these as the first-choice values for new whatnick energy-monitor BOMs unless the circuit requires different electrical performance.

| Role | Value | Package | Preferred MPN | Manufacturer | Notes |
|---|---|---|---|---|---|
| Logic/reset pull-up, LED limit, generic bias | 1 kOhm 1% | 0402 | `RC0402FR-071KL` | YAGEO | Reuse for non-precision 1 k resistors. Do not use for precision dividers when tighter specs are needed. |
| Generic pull-up/pull-down | 10 kOhm 1% | 0402 | `RC0402FR-0710KL` | YAGEO | Default digital/config strap resistor. |
| YHDC current-output clamp burden/multiplier | 2.4 Ohm 1% | 0402 | `RC0402FR-072R4L` | YAGEO | Use only where power dissipation and measurement error budget are acceptable. |
| Local high-frequency decoupling | 100 nF X7R | 0402 | `GRM155R71A104KA01D` | Murata | Default 0402 decoupler. Raise voltage rating when rail or derating requires it. |
| Reset/reference small bypass | 1 uF X5R | 0402 | `GRM155R61A105KE15D` | Murata | Default compact 1 uF. Check DC bias for analog reference use. |
| Anti-alias shunt capacitor | 22 nF X7R | 0402 | `GRM155R71H223KA12D` | Murata | ADE9000-style 1 k/22 nF first-order filters. |
| Crystal load capacitor | 16 pF C0G/NP0 | 0402 | `GRM1555C1H160JA01D` | Murata | Use C0G/NP0 for oscillator stability. Adjust value for crystal load capacitance and stray capacitance. |
| Bulk rail decoupling | 4.7 uF X5R | 0805 | `CL21A475KPFNNNE` | Samsung Electro-Mechanics | Default 0805 low-frequency local/bulk capacitor. |
| Bulk input decoupling | 10 uF X5R | 0805 | `CL21A106KPFNNNE` | Samsung Electro-Mechanics | Default 0805 10 uF. Check DC bias and voltage derating. |
| Green status LED | Green 0603 | 0603 | `LTST-C191KGKT` | Lite-On | Shared indicator LED where color is not functionally constrained. |

For larger hand-assembled bench boards such as the ADE9000 ATM-style breakout, prefer 0603 equivalents for small passives while preserving the same electrical value, tolerance, dielectric, voltage rating, and measurement role. Current ADE9000 0603 choices are `RC0603FR-071KL`, `RC0603FR-0710KL`, `RC0603FR-072R4L`, `RC0603FR-07100KL`, `RC0603FR-072K49L`, `GRM188R71A104KA61D`, `GRM188R61A105KA61D`, `GRM188R71H223KA01D`, and `GRM1885C1H160JA01D`.

## Exact Mechanical Parts

These are shared where the matching footprint and mechanical envelope are intentionally used:

| Role | Preferred MPN | Manufacturer | Notes |
|---|---|---|---|
| ADE9000 CT stereo SMT jack | `SJ-3523-SMT-TR` | Same Sky | Must match `Jack_3.5mm_CUI_SJ-3523-SMT_Horizontal` and the project-local STEP model. |
| 3.5 mm 2-position voltage terminal | `1984617` | Phoenix Contact | Preferred 3.5 mm horizontal terminal substitute for ADE9000-style voltage terminals. Verify footprint against the target board. |
| 1x16 breakaway male header for SparkFun locking footprint | `PREC016SAAN-RC` | Sullins Connector Solutions | Header body used with SparkFun staggered/friction-fit PTH footprint. |

## Schematic Fields

For each sourced symbol, populate:

- `Manufacturer`
- `MPN`
- `Description`
- `DigiKey`
- `Mouser`

Use consistent field names across repositories so BOM exporters can group by MPN. If a board has legacy fields, preserve them only when required by its existing exporter and add the standard fields as well.

## Selection Workflow

1. Group parts by value, footprint, tolerance, voltage rating, dielectric, and role.
2. Match each group against the preferred common parts table.
3. Use the preferred MPN when the group is electrically equivalent or better for that role.
4. For special measurement or safety parts, choose the correct part first and document why it differs from the preferred list.
5. Add schematic fields, then export grouped CSV/XLSX BOM outputs from schematic data.
6. Review the grouped BOM for accidental fragmentation such as `100n`, `100nF`, and `0.1uF` exporting as separate lines.
7. Check live DigiKey/Mouser stock and packaging before ordering; distributor availability changes faster than the repository.

## When Not To Reuse

Choose a different MPN when any of these differ materially:

- ADC accuracy path needs tighter tolerance, tempco, voltage coefficient, or power rating.
- Capacitor dielectric or voltage rating affects filter frequency, reference noise, startup timing, or oscillator behavior.
- Connector must match an existing enclosure, mating cable, STEP model, board edge, or assembly process.
- The preferred part is end-of-life, unavailable in useful quantity, or no longer offered in reel-friendly packaging.

## Export Discipline

- Treat the schematic as BOM source of truth.
- Generated CSV/XLSX outputs are build artifacts derived from fields, but commit them when the repository uses BOM spreadsheets for ordering.
- Keep hand-edited iBOM output separate from sourced BOM commits unless the task is specifically to regenerate iBOM.
- Prefer exporter scripts over manual copy-paste from iBOM so the same preferred MPNs can be reused across boards.

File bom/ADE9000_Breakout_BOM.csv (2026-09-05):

Line | Quantity | References | Value | Footprint | Manufacturer | MPN | DigiKey | Mouser | Description
1 | 1 | C1 | 10uF | Capacitor_SMD:C_0805_2012Metric | Samsung Electro-Mechanics | CL21A106KPFNNNE | https://www.digikey.com/en/products/result?keywords=CL21A106KPFNNNE | https://www.mouser.com/c/?q=CL21A106KPFNNNE | 10 uF 10 V X5R 0805 ceramic capacitor
2 | 4 | C2, C4, C6, C8 | 100nF | Capacitor_SMD:C_0603_1608Metric | YAGEO | CC0603KPX7R0BB104 | https://www.digikey.com.au/en/products/detail/yageo/CC0603KPX7R0BB104/29291093 | https://www.mouser.com/c/?q=CC0603KPX7R0BB104 | 100 nF 100 V 10% X7R 0603 ceramic capacitor
3 | 3 | C3, C5, C7 | 4.7uF | Capacitor_SMD:C_0805_2012Metric | Samsung Electro-Mechanics | CL21A475KPFNNNE | https://www.digikey.com/en/products/result?keywords=CL21A475KPFNNNE | https://www.mouser.com/c/?q=CL21A475KPFNNNE | 4.7 uF 10 V X5R 0805 ceramic capacitor
4 | 2 | C9, C10 | 16pF | Capacitor_SMD:C_0603_1608Metric | Murata | GRM1885C1H160JA01D | https://www.digikey.com/en/products/result?keywords=GRM1885C1H160JA01D | https://www.mouser.com/c/?q=GRM1885C1H160JA01D | 16 pF 50 V C0G/NP0 0603 ceramic capacitor
5 | 1 | C11 | 1uF | Capacitor_SMD:C_0603_1608Metric | Murata | GRM188R61A105KA61D | https://www.digikey.com/en/products/result?keywords=GRM188R61A105KA61D | https://www.mouser.com/c/?q=GRM188R61A105KA61D | 1 uF 10 V X5R 0603 ceramic capacitor
6 | 14 | C12, C13, C14, C15, C16, C17, C18, C19, C20, C21, C22, C23, C24, C25 | 22nF | Capacitor_SMD:C_0603_1608Metric | Murata | GRM188R71H223KA01D | https://www.digikey.com/en/products/result?keywords=GRM188R71H223KA01D | https://www.mouser.com/c/?q=GRM188R71H223KA01D | 22 nF 50 V X7R 0603 ceramic capacitor
7 | 4 | CTA1, CTB1, CTC1, CTN1 | CT stereo jack | Connector_Audio:Jack_3.5mm_CUI_SJ-3523-SMT_Horizontal | Same Sky | SJ-3523-SMT-TR | https://www.digikey.com/en/products/result?keywords=SJ-3523-SMT-TR | https://www.mouser.com/c/?q=SJ-3523-SMT-TR | 3.5 mm stereo SMT audio jack for current-transformer inputs
8 | 1 | D1 | GREEN_LED | LED_SMD:LED_0603_1608Metric | Lite-On | LTST-C191KGKT | https://www.digikey.com/en/products/result?keywords=LTST-C191KGKT | https://www.mouser.com/c/?q=LTST-C191KGKT | Green 0603 SMD LED
9 | 1 | J1 | Digital breadboard | SparkFun-Connector:1x16_Locking | Sullins Connector Solutions | PREC016SAAN-RC | https://www.digikey.com/en/products/result?keywords=PREC016SAAN-RC | https://www.mouser.com/c/?q=PREC016SAAN-RC | 1x16 2.54 mm vertical breakaway male header for SparkFun locking footprint
10 | 3 | J2, J3, J4 | Voltage terminal | ADE9000-Local:TerminalBlock_4Ucon_1x02_P3.50mm_Horizontal_ADE9000 | Phoenix Contact | 1984617 | https://www.digikey.com/en/products/result?keywords=1984617 | https://www.mouser.com/c/?q=1984617 | 2-position 3.5 mm horizontal screw terminal block
11 | 1 | R1 | 10k | Resistor_SMD:R_0603_1608Metric | YAGEO | RC0603FR-0710KL | https://www.digikey.com/en/products/result?keywords=RC0603FR-0710KL | https://www.mouser.com/c/?q=RC0603FR-0710KL | 10 kOhm 1% 0603 thick-film resistor
12 | 15 | R2, R3, R4, R5, R6, R7, R8, R9, R10, R11, R12, R13, R14, R15, R16 | 1k | Resistor_SMD:R_0603_1608Metric | YAGEO | RC0603FR-071KL | https://www.digikey.com/en/products/result?keywords=RC0603FR-071KL | https://www.mouser.com/c/?q=RC0603FR-071KL | 1 kOhm 1% 0603 thick-film resistor
13 | 4 | R17, R18, R19, R20 | 2.4R | Resistor_SMD:R_0603_1608Metric | YAGEO | RC0603FR-072R4L | https://www.digikey.com/en/products/result?keywords=RC0603FR-072R4L | https://www.mouser.com/c/?q=RC0603FR-072R4L | 2.4 Ohm 1% 0603 thick-film burden resistor
14 | 6 | R21, R22, R23, R24, R25, R26 | 100k | Resistor_SMD:R_0603_1608Metric | YAGEO | RC0603FR-07100KL | https://www.digikey.com/en/products/result?keywords=RC0603FR-07100KL | https://www.mouser.com/c/?q=RC0603FR-07100KL | 100 kOhm 1% 0603 voltage-divider high-side resistor
15 | 6 | R27, R28, R29, R30, R31, R32 | 2.49k | Resistor_SMD:R_0603_1608Metric | YAGEO | RC0603FR-072K49L | https://www.digikey.com/en/products/result?keywords=RC0603FR-072K49L | https://www.mouser.com/c/?q=RC0603FR-072K49L | 2.49 kOhm 1% 0603 voltage-divider shunt resistor
16 | 1 | U1 | ADE9000 | Package_DFN_QFN:QFN-40-1EP_6x6mm_P0.5mm_EP4.27x4.27mm | Analog Devices | ADE9000ACPZ | https://www.digikey.com/en/products/result?keywords=ADE9000ACPZ | https://www.mouser.com/c/?q=ADE9000ACPZ | ADE9000 polyphase energy and power quality monitoring IC, CP-40-7 LFCSP
17 | 1 | Y1 | 24.576MHz | Crystal:Crystal_SMD_3225-4Pin_3.2x2.5mm | ECS Inc. | ECS-245.7-12-33Q-JES-TR | https://www.digikey.com/en/products/result?keywords=ECS-245.7-12-33Q-JES-TR | https://www.mouser.com/c/?q=ECS-245.7-12-33Q-JES-TR | 24.576 MHz 3.2 x 2.5 mm SMD crystal

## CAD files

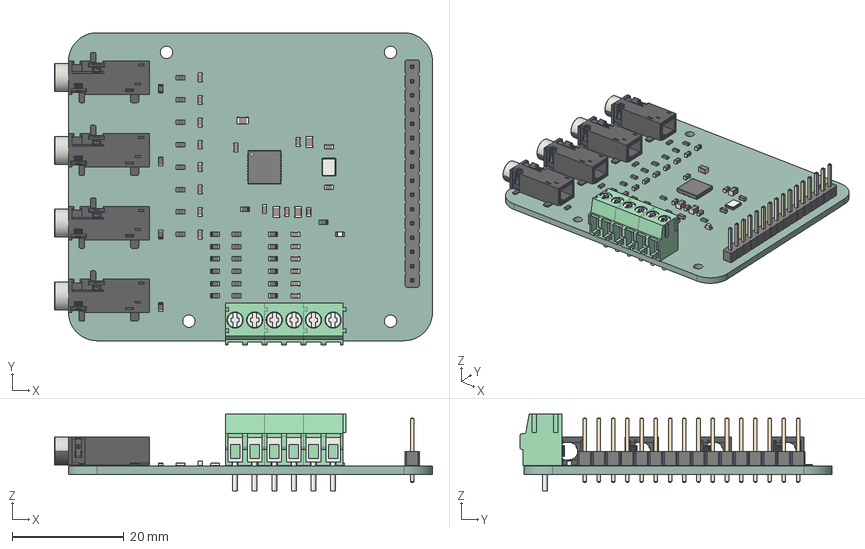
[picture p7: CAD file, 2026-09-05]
exports/step/ADE9000_Breakout.step
67.5 x 55.8 x 13.7 mm
C_0603_1608Metric x 21
R_0603_1608Metric x 32
TerminalBlock_Phoenix_PT-1,5-2-3.5-H_1x02_P3.50mm_Horizontal x 3
Jack_3.5mm_CUI_SJ-3523-SMT_Horizontal x 4
QFN-40-1EP_6x6mm_P0.5mm_EP4.6x4.6mm
C_0805_2012Metric x 4
Crystal_SMD_3225-4Pin_3.2x2.5mm
LED_0603_1608Metric
PinHeader_1x16_P2.54mm_Vertical
ADE9000_Breakout_PCB

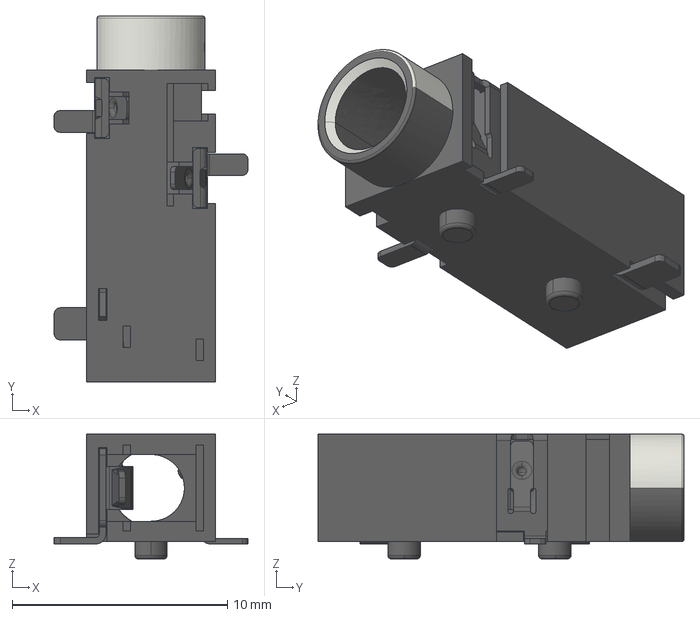
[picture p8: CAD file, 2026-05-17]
models/step/Jack_3.5mm_CUI_SJ-3523-SMT_Horizontal.step
9.00 x 17.0 x 5.80 mm

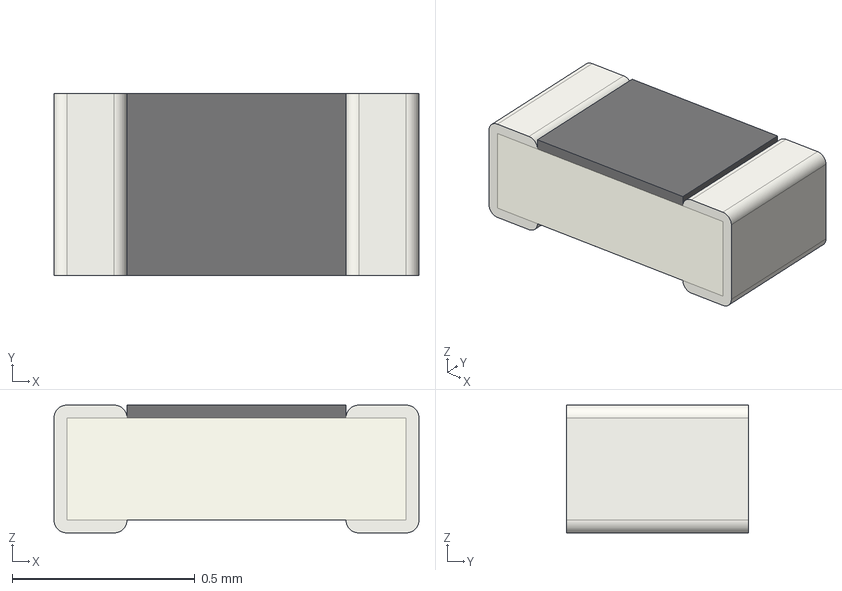
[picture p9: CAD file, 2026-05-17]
models/step/R_0402_1005Metric.step
1.00 x 0.5 x 0.35 mm

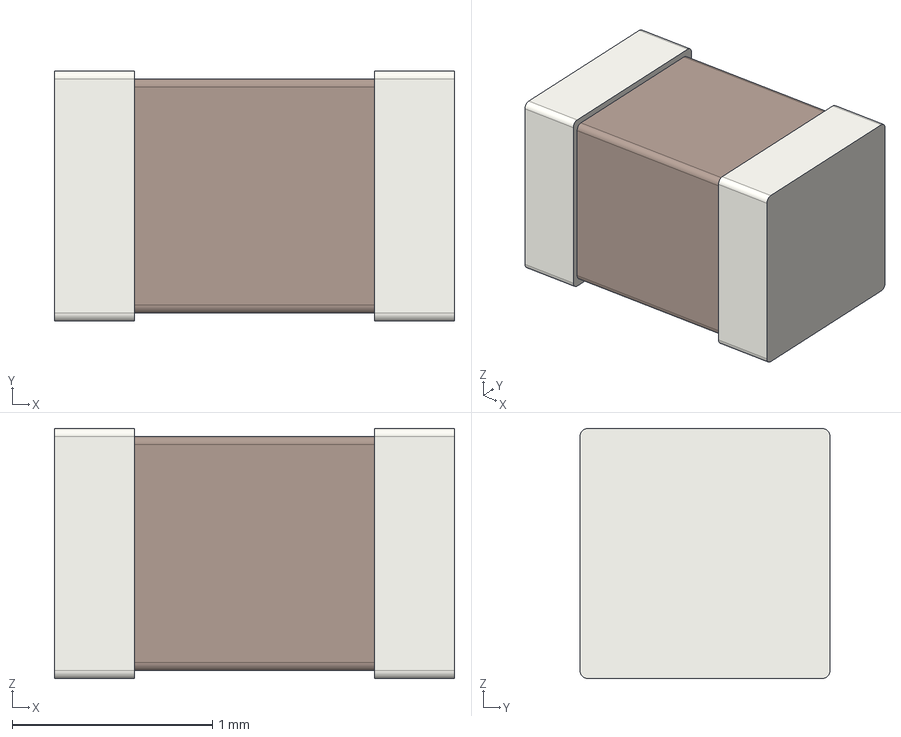
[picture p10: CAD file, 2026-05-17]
models/step/C_0805_2012Metric.step
2.00 x 1.25 x 1.25 mm

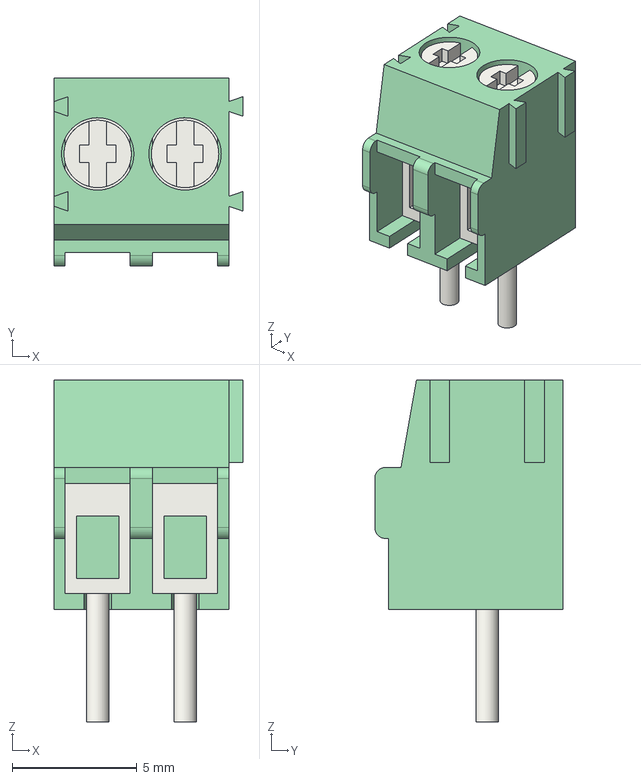
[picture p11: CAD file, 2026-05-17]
models/step/TerminalBlock_Phoenix_PT-1,5-2-3.5-H_1x02_P3.50mm_Horizontal.step
7.57 x 7.55 x 13.7 mm

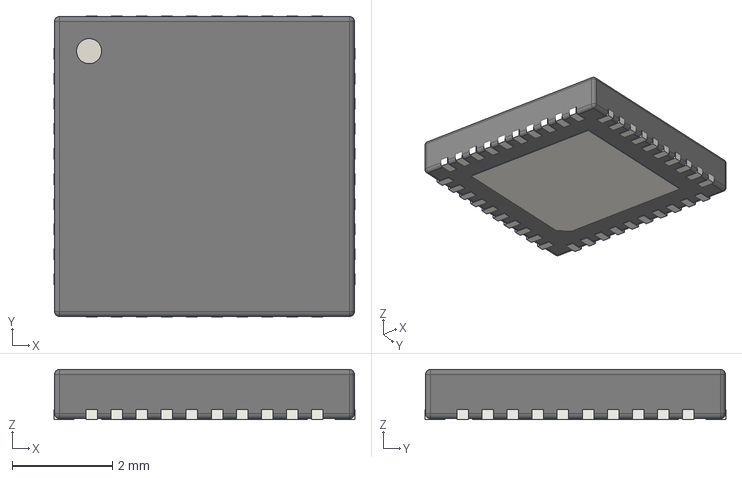
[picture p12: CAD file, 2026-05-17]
models/step/QFN-40-1EP_6x6mm_P0.5mm_EP4.6x4.6mm.step
6.00 x 6.00 x 1.00 mm

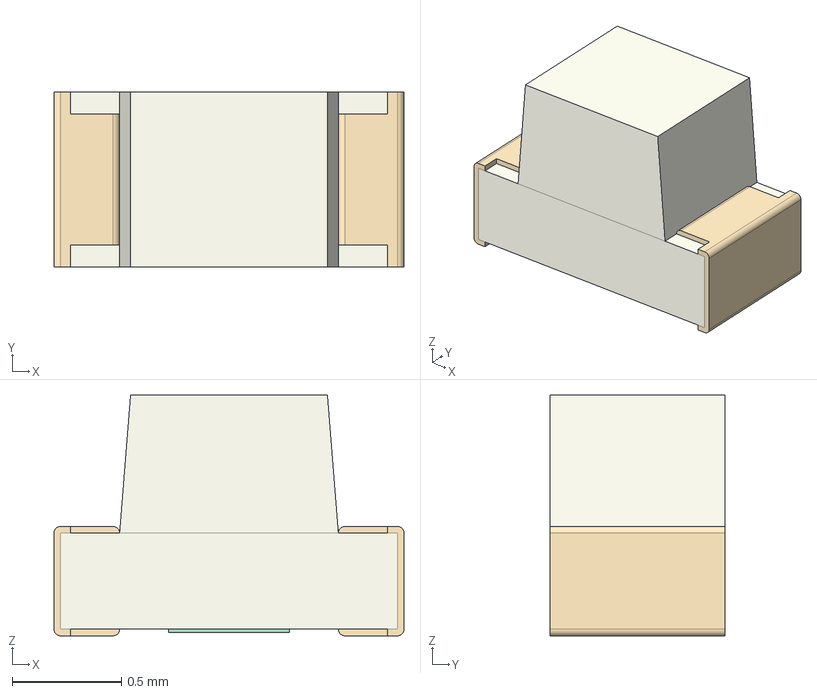
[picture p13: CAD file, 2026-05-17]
models/step/LED_0603_1608Metric.step
1.60 x 0.8 x 1.10 mm

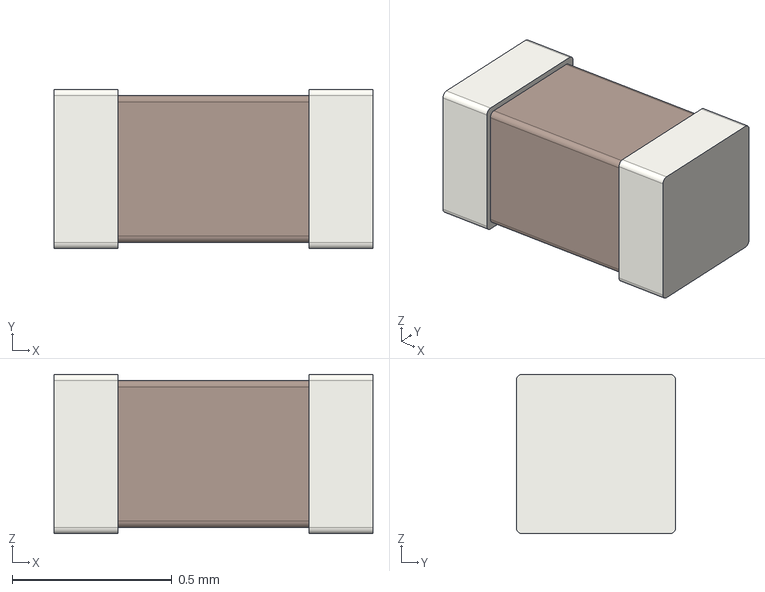
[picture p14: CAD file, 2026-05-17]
models/step/C_0402_1005Metric.step
1.00 x 0.5 x 0.5 mm

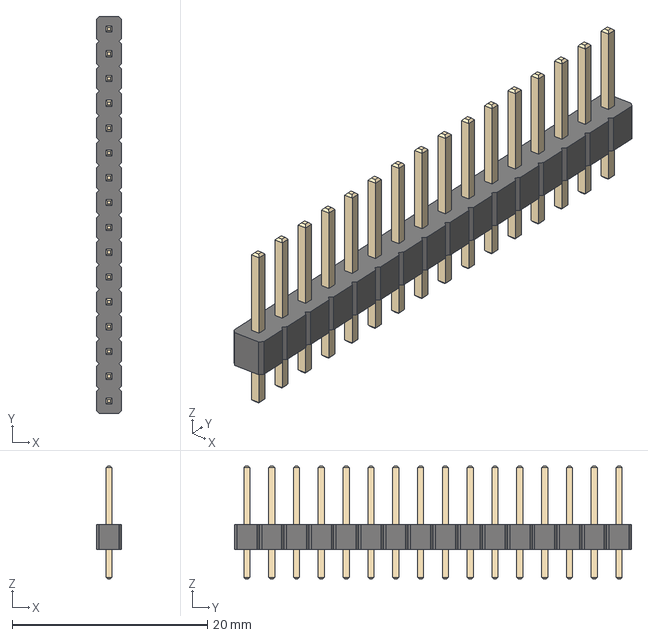
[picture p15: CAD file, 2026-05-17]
models/step/PinHeader_1x16_P2.54mm_Vertical.step
2.54 x 40.6 x 11.5 mm

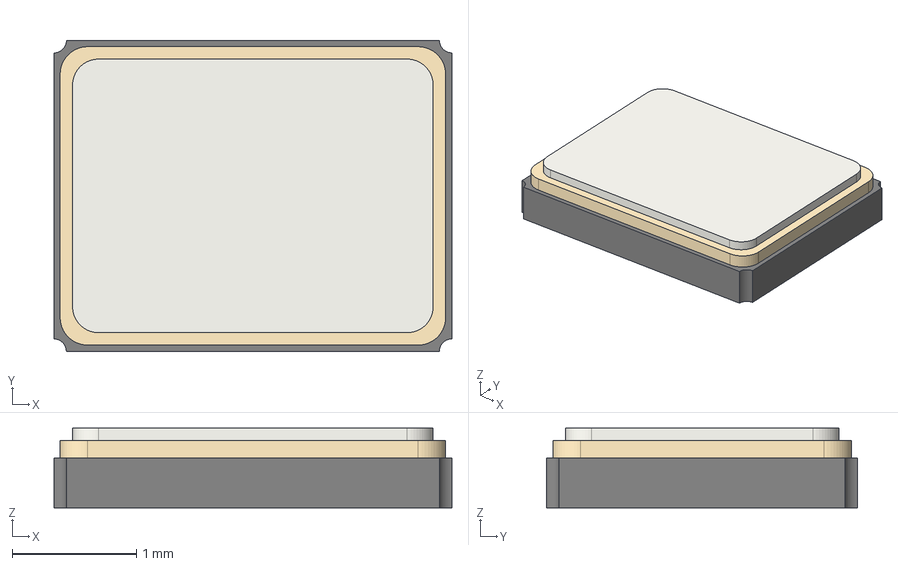
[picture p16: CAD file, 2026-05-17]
models/step/Crystal_SMD_3225-4Pin_3.2x2.5mm.step
3.20 x 2.50 x 0.64 mm

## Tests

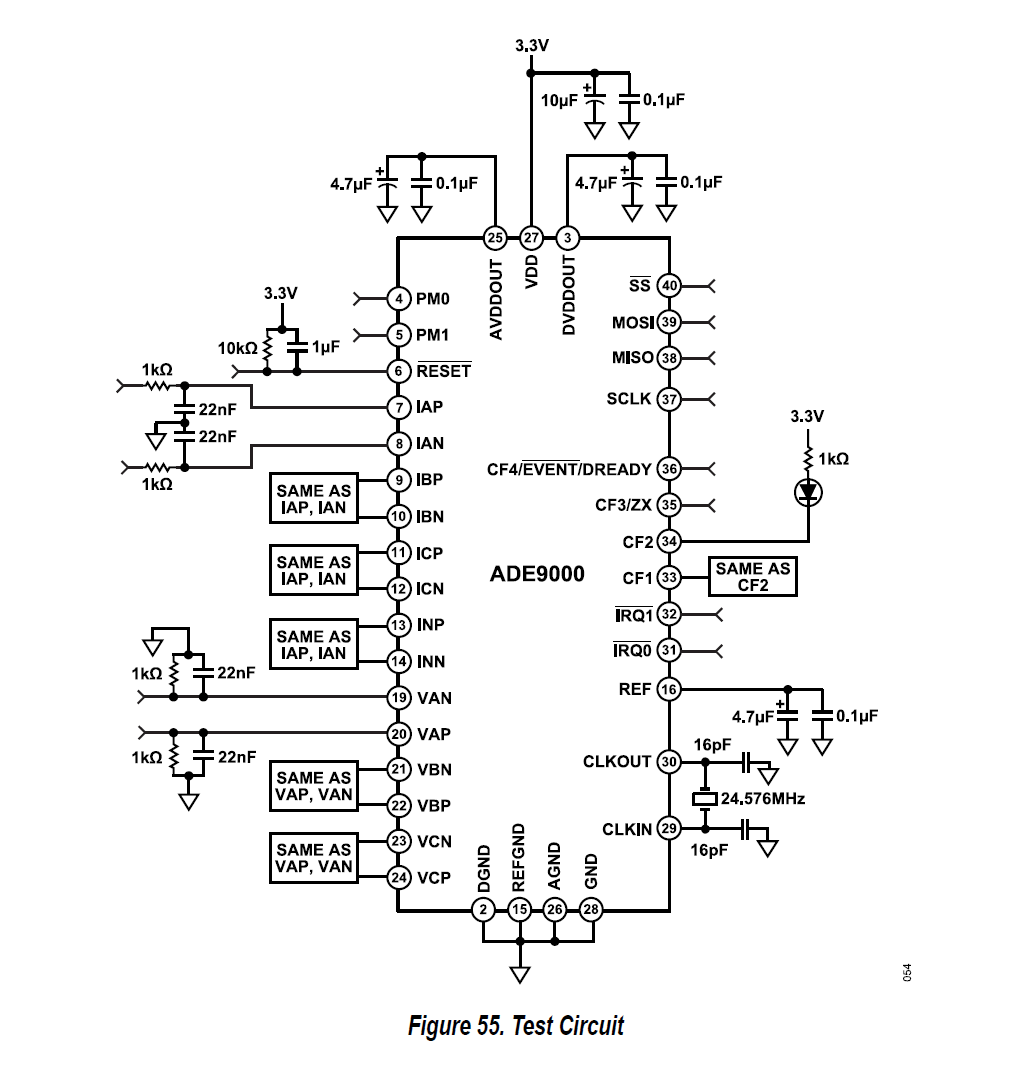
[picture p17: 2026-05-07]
docs/images/test_ade9000.png

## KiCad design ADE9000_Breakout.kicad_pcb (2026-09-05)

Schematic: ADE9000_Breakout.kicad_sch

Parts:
C1: 10uF; C_0805_2012Metric; MPN CL21A106KPFNNNE
C2, C4, C6, C8: 100nF; C_0603_1608Metric; MPN CC0603KPX7R0BB104
C3, C5, C7: 4.7uF; C_0805_2012Metric; MPN CL21A475KPFNNNE
C9, C10: 16pF; C_0603_1608Metric; MPN GRM1885C1H160JA01D
C11: 1uF; C_0603_1608Metric; MPN GRM188R61A105KA61D
C12, C13, C14, C15, C16, C17, C18, C19, C20, C21, C22, C23, C24, C25: 22nF; C_0603_1608Metric; MPN GRM188R71H223KA01D
CTA1: CT stereo jack; Jack_3.5mm_CUI_SJ-3523-SMT_Horizontal; MPN SJ-3523-SMT-TR
CTB1: CT stereo jack; Jack_3.5mm_CUI_SJ-3523-SMT_Horizontal; MPN SJ-3523-SMT-TR
CTC1: CT stereo jack; Jack_3.5mm_CUI_SJ-3523-SMT_Horizontal; MPN SJ-3523-SMT-TR
CTN1: CT stereo jack; Jack_3.5mm_CUI_SJ-3523-SMT_Horizontal; MPN SJ-3523-SMT-TR
D1: GREEN_LED; LED_0603_1608Metric; MPN LTST-C191KGKT
J1: Digital breadboard; 1x16_Locking; MPN PREC016SAAN-RC
J2, J3, J4: Voltage terminal; TerminalBlock_4Ucon_1x02_P3.50mm_Horizontal_ADE9000; MPN 1984617
JP1: PM0 mode; ModeBridge_3Pad
JP2: PM1 mode; ModeBridge_3Pad
R1: 10k; R_0603_1608Metric; MPN RC0603FR-0710KL
R2, R3, R4, R5, R6, R7, R8, R9, R10, R11, R12, R13, R14, R15, R16: 1k; R_0603_1608Metric; MPN RC0603FR-071KL
R17, R18, R19, R20: 2.4R; R_0603_1608Metric; MPN RC0603FR-072R4L
R21, R22, R23, R24, R25, R26: 100k; R_0603_1608Metric; MPN RC0603FR-07100KL
R27, R28, R29, R30, R31, R32: 2.49k; R_0603_1608Metric; MPN RC0603FR-072K49L
U1: ADE9000; QFN-40-1EP_6x6mm_P0.5mm_EP4.27x4.27mm; MPN ADE9000ACPZ
Y1: 24.576MHz; Crystal_SMD_3225-4Pin_3.2x2.5mm; MPN ECS-245.7-12-33Q-JES-TR

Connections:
+3V3: C1.2, C2.2, J1.1, JP1.1 (A), JP2.1 (A), R1.2, U1.1 (PULL_HIGH), U1.27 (VDD)
AVDDOUT: C3.2, C4.2, U1.25 (AVDDOUT)
CF1: J1.9, U1.33 (CF1)
CF2: J1.10, R16.2, U1.34 (CF2)
CF2_LED: D1.2 (A), R16.1
CF3_ZX: J1.11, U1.35 (CF3/ZX)
CF4_DREADY: J1.12, U1.36 (CF4/~DREADY)
CLKIN: C9.2, J1.14, U1.29 (CLKIN), Y1.1
CLKOUT: C10.2, J1.15, U1.30 (CLKOUT), Y1.2
DVDDOUT: C5.2, C6.2, U1.3 (DVDDOUT)
GND: C1.1, C2.1, C3.1, C4.1, C5.1, C6.1, C7.1, C8.1, C9.1, C10.1, C11.1, C12.2, C13.2, C14.2, C15.2, C16.2, C17.2, C18.2, C19.2, C20.2, C21.2, C22.2, C23.2, C24.2, C25.2, CTA1.R, CTB1.R, CTC1.R, CTN1.R, D1.1 (K), J1.2, J1.16, JP1.3 (B), JP2.3 (B), R27.2, R28.2, R29.2, R30.2, R31.2, R32.2, U1.2 (DGND), U1.15 (REFGND), U1.26 (AGND), U1.28 (GND), U1.EP (EPAD)
IAN: C13.1, R3.2, U1.8 (IAN)
IAN_J: CTA1.S, R3.1, R17.2
IAP: C12.1, R2.2, U1.7 (IAP)
IAP_J: CTA1.T, R2.1, R17.1
IBN: C15.1, R5.2, U1.10 (IBN)
IBN_J: CTB1.S, R5.1, R18.2
IBP: C14.1, R4.2, U1.9 (IBP)
IBP_J: CTB1.T, R4.1, R18.1
ICN: C17.1, R7.2, U1.12 (ICN)
ICN_J: CTC1.S, R7.1, R19.2
ICP: C16.1, R6.2, U1.11 (ICP)
ICP_J: CTC1.T, R6.1, R19.1
INN: C19.1, R9.2, U1.14 (INN)
INN_J: CTN1.S, R9.1, R20.2
INP: C18.1, R8.2, U1.13 (INP)
INP_J: CTN1.T, R8.1, R20.1
IRQ0: J1.7, U1.31 (~IRQ0)
IRQ1: J1.8, U1.32 (~IRQ1)
MISO: J1.5, U1.38 (MISO)
MOSI: J1.4, U1.39 (MOSI)
PM0: JP1.2 (C), U1.4 (PM0)
PM1: JP2.2 (C), U1.5 (PM1)
REF: C7.2, C8.2, U1.16 (REF)
RESET: C11.2, J1.13, R1.1, U1.6 (~RESET)
SCLK: J1.6, U1.37 (SCLK)
SS: J1.3, U1.40 (~SS)
VAN: C20.1, R10.2, U1.19 (VAN)
VAN_DIV: R10.1, R22.2, R28.1
VAN_J: J2.2, R22.1
VAP: C21.1, R11.2, U1.20 (VAP)
VAP_DIV: R11.1, R21.2, R27.1
VAP_J: J2.1, R21.1
VBN: C22.1, R12.2, U1.21 (VBN)
VBN_DIV: R12.1, R24.2, R30.1
VBN_J: J3.2, R24.1
VBP: C23.1, R13.2, U1.22 (VBP)
VBP_DIV: R13.1, R23.2, R29.1
VBP_J: J3.1, R23.1
VCN: C24.1, R14.2, U1.23 (VCN)
VCN_DIV: R14.1, R26.2, R32.1
VCN_J: J4.2, R26.1
VCP: C25.1, R15.2, U1.24 (VCP)
VCP_DIV: R15.1, R25.2, R31.1
VCP_J: J4.1, R25.1

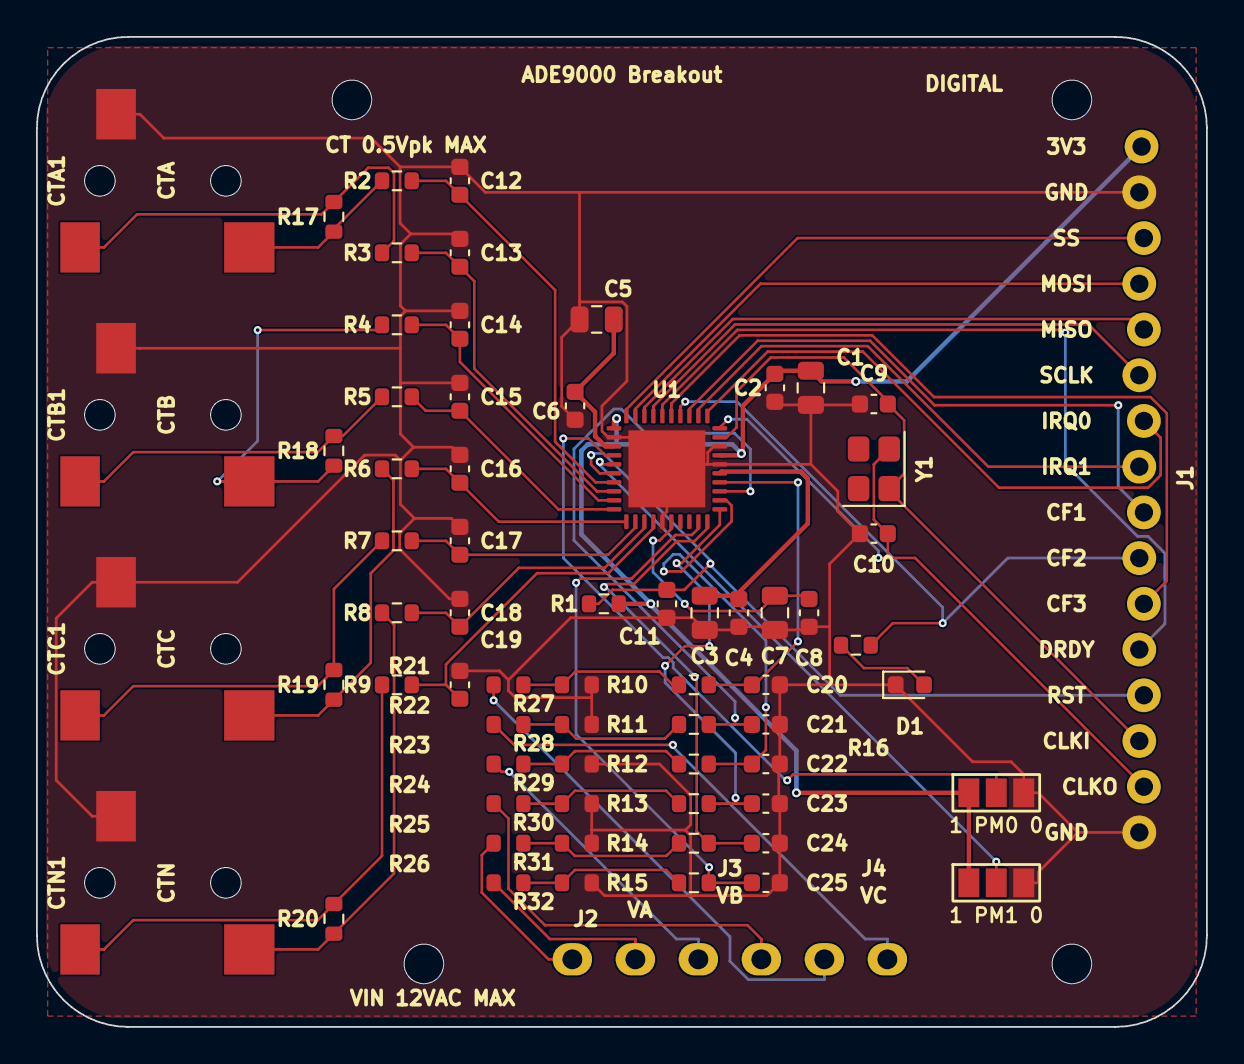
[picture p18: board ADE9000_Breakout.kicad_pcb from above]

Board: 2 copper layers, 65.0 x 55.0 mm, 75 parts (1 on the bottom side), 55 nets.

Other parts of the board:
H1, H2, H3, H4: MountingHole_2.2mm_M2
LOGO1: OSHW-LOGOM; OSHW-Logo2_7.3x6mm_SilkScreen

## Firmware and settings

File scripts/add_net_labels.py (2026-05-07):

"""
ADE9000 Breakout Board - Net Label Adder
Adds all net labels to connect schematic components.

Net strategy:
- J1 pin1 → +3V3 label
- J1 pin2 → GND label
- J2/J3 connector pins → IAP_J, IAN_J ... nets (left side of resistors)
- Resistors R2..R15 connect IAP_J → IAP through 1kΩ
- Caps C12..C25 connect node IAP etc → GND
- U1 analog pins get IAP, IAN... labels
- U1 digital pins get test pad labels
- Test pads TP1..TP11 get matching labels
- Power ties: PULL_HIGH→+3V3, PM0→GND, PM1→GND, DGND→GND, AGND→GND, REFGND→GND, EPAD→GND

Label angle convention:
- angle=0   → label faces RIGHT (normal, wire extends to the left)
- angle=180 → label faces LEFT (wire extends to the right)
"""
import sys
import json
import subprocess

SCH_PATH = r"c:\Users\tisha\dev\ADE9000_Breakout\ADE9000_Breakout.kicad_sch"
KI_IFACE = r"c:\Users\tisha\dev\KiCAD-MCP-Server\python\kicad_interface.py"
KI_PYTHON = r"C:\Program Files\KiCad\10.0\bin\python.exe"

def call_iface(command: str, params: dict):
    payload = json.dumps({"command": command, "params": params})
    result = subprocess.run(
        [KI_PYTHON, KI_IFACE],
        input=payload, capture_output=True, text=True, timeout=30
    )
    try:
        data = json.loads(result.stdout)
    except Exception:
        data = {"success": False, "stdout": result.stdout, "stderr": result.stderr}
    if not data.get("success"):
        print(f"  WARN: {command} '{params.get('label', params.get('x', ''))}' failed: {data.get('message', data)[:80]}", file=sys.stderr)
    return data

def label(net: str, x: float, y: float, angle: int = 0):
    return call_iface("add_schematic_net_label", {
        "schematicPath": SCH_PATH,
        "netName": net,
        "position": [x, y],
        "orientation": angle,
    })

def no_connect(x: float, y: float):
    return call_iface("add_no_connect", {
        "schematicPath": SCH_PATH, "position": [x, y]
    })

ok = lambda r: "✓" if r.get("success") else "✗"

print("=== ADE9000 Net Label Adder ===\n")

# ─── PIN POSITIONS ─────────────────────────────────────────────────────────────
# U1 left pins wire at x=117.3; U1 right pins wire at x=142.7
U1_LX = 117.3
U1_RX = 142.7

# For labels ON U1 left wires (facing left, so net comes from left):
# angle=0 means text faces right → the wire end attaches left of label
# We want a label pointing INTO the wire end at x=117.3
# Use angle=180 so the connection point is on the RIGHT side of the label,
# placed just past the wire end.
# KiCad net label: the connection stub is at the label origin (x,y).
# angle=0: connection stub on left, text extends right.
# angle=180: connection stub on right, text extends left.
# For U1 left pins, wire ends are at x=117.3 pointing LEFT (toward x<117.3).
# So we place label at x=117.3 with angle=0 (stub on left matches wire going left).
# For U1 right pins, wire ends at x=142.7 pointing RIGHT (toward x>142.7).
# Place label at x=142.7 with angle=180 (stub on right matches wire going right).

print("--- U1 Left Pin Labels (analog + control) ---")
left_pin_labels = [
    # (net_name, x, y)
    ("+3V3",   U1_LX, 70.79),   # PULL_HIGH  (pin1)  → +3V3
    ("GND",    U1_LX, 73.33),   # DGND       (pin2)  → GND
    # DVDDOUT (pin3) gets its own node: DVDDOUT net (power output)
    ("GND",    U1_LX, 78.41),   # PM0        (pin4)  → GND (SPI mode)
    ("GND",    U1_LX, 80.95),   # PM1        (pin5)  → GND (normal mode)
    ("RESET",  U1_LX, 83.49),   # ~RESET~    (pin6)
    # Analog current inputs
    ("IAP",    U1_LX, 86.03),
    ("IAN",    U1_LX, 88.57),
    ("IBP",    U1_LX, 91.11),
    ("IBN",    U1_LX, 93.65),
    ("ICP",    U1_LX, 96.19),
    ("ICN",    U1_LX, 98.73),
    ("INP",    U1_LX, 101.27),
    ("INN",    U1_LX, 103.81),
    ("GND",    U1_LX, 106.35),  # REFGND     (pin15) → GND
    ("REF",    U1_LX, 108.89),  # REF output (pin16)
    # NC1/NC2 → no-connect, handled separately
    # Analog voltage inputs
    ("VAN",    U1_LX, 116.51),
    ("VAP",    U1_LX, 119.05),
    ("VBN",    U1_LX, 121.59),
    ("VBP",    U1_LX, 124.13),
    ("VCN",    U1_LX, 126.67),
    ("VCP",    U1_LX, 129.21),
]

for net, x, y in left_pin_labels:
    r = label(net, x, y, angle=0)
    print(f"  {ok(r)} label '{net}' @ ({x}, {y:.2f})")

# DVDDOUT output node label
r = label("DVDDOUT", U1_LX, 75.87, angle=0)
print(f"  {ok(r)} label 'DVDDOUT' @ ({U1_LX}, 75.87)")

print()
print("--- U1 Right Pin Labels (power + SPI + CF) ---")
right_pin_labels = [
    # (net_name, x, y)
    ("AVDDOUT", U1_RX, 79.68),   # pin25
    ("GND",     U1_RX, 82.22),   # AGND (pin26) → GND
    ("+3V3",    U1_RX, 84.76),   # VDD  (pin27) → +3V3 in
    ("GND",     U1_RX, 87.30),   # GND  (pin28)
    ("CLKIN",   U1_RX, 89.84),   # CLKIN (pin29)
    ("CLKOUT",  U1_RX, 92.38),   # CLKOUT (pin30)
    ("IRQ0",    U1_RX, 94.92),   # ~IRQ0~ (pin31)
    ("IRQ1",    U1_RX, 97.46),   # ~IRQ1~ (pin32)
    ("CF1",     U1_RX, 100.00),  # CF1 (pin33)
    ("CF2",     U1_RX, 102.54),  # CF2 (pin34)
    ("CF3_ZX",  U1_RX, 105.08),  # CF3/ZX (pin35)
    ("CF4_DREADY", U1_RX, 107.62),  # CF4/DREADY (pin36)
    ("SCLK",    U1_RX, 110.16),  # SCLK (pin37)
    ("MISO",    U1_RX, 112.70),  # MISO (pin38)
    ("MOSI",    U1_RX, 115.24),  # MOSI (pin39)
    ("SS",      U1_RX, 117.78),  # ~SS~ (pin40)
    ("GND",     U1_RX, 120.32),  # EPAD → GND
]

for net, x, y in right_pin_labels:
    r = label(net, x, y, angle=180)
    print(f"  {ok(r)} label '{net}' @ ({x}, {y:.2f})")

# ─── NO-CONNECTS for NC1, NC2 ─────────────────────────────────────────────────
print()
print("--- No-Connects ---")
r = no_connect(U1_LX, 111.43)
print(f"  {ok(r)} no-connect NC1 @ ({U1_LX}, 111.43)")
r = no_connect(U1_LX, 113.97)
print(f"  {ok(r)} no-connect NC2 @ ({U1_LX}, 113.97)")

# ─── J1 POWER CONNECTOR ──────────────────────────────────────────────────────
# Conn_01x02 at (35, 72)
# Pin1 at (29.92, 72.00), Pin2 at (29.92, 69.46)
print()
print("--- J1 Power Connector ---")
# J1 connector pin ends are on the LEFT side of the connector (at x ≈ 29.92)
# Labels face right (angle=0) connecting to the stub
r = label("+3V3", 29.92, 72.00, angle=180)
print(f"  {ok(r)} label '+3V3' J1-pin1")
r = label("GND",  29.92, 69.46, angle=180)
print(f"  {ok(r)} label 'GND'  J1-pin2")

# ─── J2 CURRENT CONNECTOR ────────────────────────────────────────────────────
# Conn_01x08 at (35, 96.19) — pin ends at x=29.92
# Pin y-positions: pin1(bottom)=103.81, pin2=101.27, ..., pin8(top)=86.03
# Net assignment (bottom=pin1=INN, top=pin8=IAP):
print()
print("--- J2 Current Connector ---")
j2_pins = [
    (29.92, 103.81, "INN_J"),  # pin1
    (29.92, 101.27, "INP_J"),  # pin2
    (29.92,  98.73, "ICN_J"),  # pin3
    (29.92,  96.19, "ICP_J"),  # pin4
    (29.92,  93.65, "IBN_J"),  # pin5
    (29.92,  91.11, "IBP_J"),  # pin6
    (29.92,  88.57, "IAN_J"),  # pin7
    (29.92,  86.03, "IAP_J"),  # pin8
]
for x, y, net in j2_pins:
    r = label(net, x, y, angle=180)
    print(f"  {ok(r)} label '{net}' @ ({x}, {y:.2f})")
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

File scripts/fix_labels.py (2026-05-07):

"""
ADE9000 Breakout - Label Fixer
Clears ALL labels from the schematic and re-adds with CORRECT positions.

Root cause of issues discovered via PinLocator:
1. ADE9000 symbol has pins in REVERSED y-order from what was assumed.
   - pin24 (VCP) is at the TOP of U1's left side (y=70.79)
   - pin1 (PULL_HIGH) is at the BOTTOM (y=129.21)
   - Same for right side: EPAD at top (y=79.68), AVDDOUT at bottom (y=120.32)
2. KiCad symbol y-axis in schematic is INVERTED from symbol file y-axis.
   - Correct formula: schematic_y = component_y - symbol_pin_y
   - My original script incorrectly used: component_y + symbol_pin_y
3. Test pad labels were at x=162.46 but pins are at x=159.92 (Conn_01x01 pin at -5.08, not -2.54)
4. J2/J3 connector net assignments were scrambled due to #2 above
5. D1 (LED) has horizontal pins at y=106 but labels were placed vertically

All positions verified by PinLocator.get_pin_location() from KiCad MCP Server.
"""
import sys
import json
import re
import subprocess
from pathlib import Path

SCH_PATH = r"c:\Users\tisha\dev\ADE9000_Breakout\ADE9000_Breakout.kicad_sch"
KI_IFACE = r"c:\Users\tisha\dev\KiCAD-MCP-Server\python\kicad_interface.py"
KI_PYTHON = r"C:\Program Files\KiCad\10.0\bin\python.exe"


# ─── STEP 1: CLEAR ALL LABELS FROM SCHEMATIC FILE ────────────────────────────

def remove_sexp_blocks(content: str, keyword: str) -> str:
    """Remove all top-level S-expression blocks starting with (keyword ...)."""
    result = []
    i = 0
    search_term = f'({keyword} '
    while i < len(content):
        idx = content.find(search_term, i)
        if idx == -1:
            result.append(content[i:])
            break
        # Add everything before this block
        result.append(content[i:idx])
        # Count parentheses to find the end of this S-expression block
        depth = 0
        j = idx
        while j < len(content):
            if content[j] == '(':
                depth += 1
            elif content[j] == ')':
                depth -= 1
                if depth == 0:
                    j += 1
                    break
            j += 1
        # Skip (don't include) this block; also skip trailing whitespace/newline
        while j < len(content) and content[j] in ' \t\r\n':
            j += 1
        i = j
    return ''.join(result)


print("=== Step 1: Clear existing labels and no-connects ===")
sch = Path(SCH_PATH)
content = sch.read_text(encoding='utf-8')

label_count = content.count('(label ')
nc_count = content.count('(no_connect ')
print(f"  Found {label_count} labels and {nc_count} no-connects")

content = remove_sexp_blocks(content, 'label')
content = remove_sexp_blocks(content, 'no_connect')

sch.write_text(content, encoding='utf-8')
print(f"  Cleared {label_count} labels and {nc_count} no-connects ✓")


# ─── STEP 2: RE-ADD ALL LABELS WITH CORRECT POSITIONS ────────────────────────

def call_iface(command: str, params: dict):
    payload = json.dumps({"command": command, "params": params})
    result = subprocess.run(
        [KI_PYTHON, KI_IFACE],
        input=payload, capture_output=True, text=True, timeout=30
    )
    try:
        data = json.loads(result.stdout)
    except Exception:
        data = {"success": False, "message": result.stderr[:120]}
    return data


def label(net: str, x: float, y: float, angle: int = 0):
    return call_iface("add_schematic_net_label", {
        "schematicPath": SCH_PATH,
        "netName": net,
        "position": [x, y],
        "orientation": angle,
    })


def no_connect(x: float, y: float):
    return call_iface("add_no_connect", {
        "schematicPath": SCH_PATH,
        "position": [x, y],
    })


ok = lambda r: "✓" if r.get("success") else f"✗({r.get('message','?')[:40]})"

errors = 0


def lbl(net, x, y, angle=0):
    global errors
    r = label(net, x, y, angle)
    status = ok(r)
    if not r.get("success"):
        errors += 1
        print(f"  ✗ label '{net}' @ ({x:.2f},{y:.2f}): {r.get('message','?')[:60]}")
    return r


def nc(x, y):
    global errors
    r = no_connect(x, y)
    if not r.get("success"):
        errors += 1
        print(f"  ✗ no_connect @ ({x:.2f},{y:.2f}): {r.get('message','?')[:60]}")
    return r


print()
print("=== Step 2: Add corrected U1 labels ===")
print()

# U1 LEFT SIDE (x=117.3, angle=0 — labels face right, stub on left)
# Pins verified by PinLocator. ADE9000 symbol has REVERSED pin order:
# physical pin 24 (VCP) at y=70.79 (TOP), physical pin 1 (PULL_HIGH) at y=129.21 (BOTTOM)
U1_LX = 117.3
U1_RX = 142.7

print("--- U1 Left Side (pins at x=117.3) ---")
# Format: (net_name, y_position, comment)
u1_left = [
    ("VCP",     70.79,  "pin24 VCP"),
    ("VCN",     73.33,  "pin23 VCN"),
    ("VBP",     75.87,  "pin22 VBP"),
    ("VBN",     78.41,  "pin21 VBN"),
    ("VAP",     80.95,  "pin20 VAP"),
    ("VAN",     83.49,  "pin19 VAN"),
    # pin18 NC at 86.03 → no_connect
    # pin17 NC at 88.57 → no_connect
    ("REF",     91.11,  "pin16 REF"),
    ("GND",     93.65,  "pin15 REFGND→GND"),
    ("INN",     96.19,  "pin14 INN"),
    ("INP",     98.73,  "pin13 INP"),
    ("ICN",     101.27, "pin12 ICN"),
    ("ICP",     103.81, "pin11 ICP"),
    ("IBN",     106.35, "pin10 IBN"),
    ("IBP",     108.89, "pin9 IBP"),
    ("IAN",     111.43, "pin8 IAN"),
    ("IAP",     113.97, "pin7 IAP"),
    ("RESET",   116.51, "pin6 ~RESET~"),
    ("GND",     119.05, "pin5 PM1→GND"),
    ("GND",     121.59, "pin4 PM0→GND"),
    ("DVDDOUT", 124.13, "pin3 DVDDOUT"),
    ("GND",     126.67, "pin2 DGND→GND"),
    ("+3V3",    129.21, "pin1 PULL_HIGH→+3V3"),
]
for net, y, comment in u1_left:
    r = lbl(net, U1_LX, y, angle=0)
    print(f"  {ok(r)} {net:14s} y={y:.2f}  [{comment}]")

# No-connects for NC pins (pin17 at y=88.57, pin18 at y=86.03)
r = nc(U1_LX, 86.03)
print(f"  {ok(r)} no-connect pin18 (NC) @ y=86.03")
r = nc(U1_LX, 88.57)
print(f"  {ok(r)} no-connect pin17 (NC) @ y=88.57")

print()
print("--- U1 Right Side (pins at x=142.7) ---")
# EPAD at y=79.68 (TOP), AVDDOUT at y=120.32 (BOTTOM)
u1_right = [
    ("GND",          79.68,  "EPAD→GND"),
    ("SS",           82.22,  "pin40 ~SS~"),
    ("MOSI",         84.76,  "pin39 MOSI"),
    ("MISO",         87.30,  "pin38 MISO"),
    ("SCLK",         89.84,  "pin37 SCLK"),
    ("CF4_DREADY",   92.38,  "pin36 CF4/DREADY"),
    ("CF3_ZX",       94.92,  "pin35 CF3/ZX"),
    ("CF2",          97.46,  "pin34 CF2"),
    ("CF1",          100.00, "pin33 CF1"),
    ("IRQ1",         102.54, "pin32 ~IRQ1~"),
    ("IRQ0",         105.08, "pin31 ~IRQ0~"),
    ("CLKOUT",       107.62, "pin30 CLKOUT"),
    ("CLKIN",        110.16, "pin29 CLKIN"),
    ("GND",          112.70, "pin28 GND"),
    ("+3V3",         115.24, "pin27 VDD→+3V3"),
    ("GND",          117.78, "pin26 AGND→GND"),
    ("AVDDOUT",      120.32, "pin25 AVDDOUT"),
]
for net, y, comment in u1_right:
    r = lbl(net, U1_RX, y, angle=180)
    print(f"  {ok(r)} {net:14s} y={y:.2f}  [{comment}]")
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

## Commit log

2026-05-07 Initial AI Creation
    [ADE9000_Breakout.kicad_pcb, ADE9000_Breakout.kicad_sch]
2026-05-07 Make PCB and design skills
    [ADE9000_Breakout.kicad_pcb]
2026-05-07 Complete routing
    [ADE9000_Breakout.kicad_pcb]
2026-05-08 Some silk screen vagaries
    [ADE9000_Breakout.kicad_pcb]
2026-05-09 Reroute with JST connector for SPI
    [ADE9000_Breakout.kicad_pcb, ADE9000_Breakout.kicad_sch]
2026-05-09 Move decoupling closer
    [ADE9000_Breakout.kicad_pcb]
2026-05-11 Relayout using connectors for analog inputs
    [ADE9000_Breakout.kicad_pcb, ADE9000_Breakout.kicad_sch]
2026-05-16 Rerouted with Groundplanes and new skills
    [ADE9000_Breakout.kicad_pcb, ADE9000_Breakout.kicad_sch]
2026-05-16 Added License
    [ADE9000_Breakout.kicad_pcb]
2026-05-17 Add project-local 3D CAD assets
    [ADE9000_Breakout.kicad_pcb, ADE9000_Breakout.step, C_0402_1005Metric.step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]
2026-05-17 Fix CT jack STEP orientation
    [ADE9000_Breakout.step, Jack_3.5mm_CUI_SJ-3523-SMT_Horizontal.step]
2026-05-17 Remove CT jack pad overlays
    [ADE9000_Breakout.step, Jack_3.5mm_CUI_SJ-3523-SMT_Horizontal.step]
2026-05-18 Align voltage terminal models
    [ADE9000_Breakout.kicad_pcb, ADE9000_Breakout.step]
2026-05-18 Mirror manual terminal model alignment
    [ADE9000_Breakout.kicad_pcb, ADE9000_Breakout.step]
2026-05-18 Clear silkscreen DRC warnings
    [ADE9000_Breakout.kicad_pcb]
2026-05-18 Use SparkFun locking digital header
    [ADE9000_Breakout.kicad_pcb, ADE9000_Breakout.kicad_sch, ADE9000_Breakout.step]
2026-05-18 Add sourced BOM export flow
    [ADE9000_Breakout.kicad_sch, ADE9000_Breakout_BOM.csv, ADE9000_Breakout_BOM.xlsx]
2026-05-18 Add reusable BOM sourcing skill
2026-05-18 Ibom restore
    [ADE9000_Breakout.kicad_sch, ADE9000_Breakout_BOM.xlsx]
2026-05-18 Add 12 VAC voltage input support
    [ADE9000_Breakout.kicad_pcb, ADE9000_Breakout.kicad_sch, ADE9000_Breakout_BOM.csv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]
2026-05-18 Move SMD parts to front side
    [ADE9000_Breakout.kicad_pcb, ADE9000_Breakout.step]
2026-05-18 Use 0603 passives for hand assembly
    [ADE9000_Breakout.kicad_pcb, ADE9000_Breakout.kicad_sch, ADE9000_Breakout.step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]
2026-05-19 Add upscaling parts
    [ADE9000_Breakout.kicad_pcb]
2026-08-31 Output gerbers
    [ADE9000_Breakout.kicad_pcb]
2026-09-05 Add selectable ADE9000 power modes
    Add ATM-style PM0/PM1 solder bridges, regenerate the routed board and BOM, and publish populated isometric renders in the README.\n\nCo-authored-by: Copilot <223556219+Copilot@users.noreply.github.co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
    [ADE9000_Breakout.kicad_pcb, ADE9000_Breakout.kicad_sch, ADE9000_Breakout.step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]

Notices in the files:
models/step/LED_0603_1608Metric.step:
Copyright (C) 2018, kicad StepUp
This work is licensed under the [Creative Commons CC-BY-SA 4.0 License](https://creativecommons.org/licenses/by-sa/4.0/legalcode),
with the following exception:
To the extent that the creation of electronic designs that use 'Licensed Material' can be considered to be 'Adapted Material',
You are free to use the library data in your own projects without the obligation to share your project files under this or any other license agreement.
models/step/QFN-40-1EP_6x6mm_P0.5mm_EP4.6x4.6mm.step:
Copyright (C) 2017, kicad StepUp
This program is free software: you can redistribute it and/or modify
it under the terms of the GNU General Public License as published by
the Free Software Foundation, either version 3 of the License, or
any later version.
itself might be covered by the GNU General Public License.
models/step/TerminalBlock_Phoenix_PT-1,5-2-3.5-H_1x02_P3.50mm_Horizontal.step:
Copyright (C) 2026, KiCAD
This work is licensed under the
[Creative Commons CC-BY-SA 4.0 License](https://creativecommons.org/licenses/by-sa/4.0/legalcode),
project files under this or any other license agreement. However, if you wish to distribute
